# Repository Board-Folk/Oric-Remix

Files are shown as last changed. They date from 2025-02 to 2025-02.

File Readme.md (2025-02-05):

# Oric Remix

An updated Oric-1 / Oric Atmos board

** Work-in-progress **

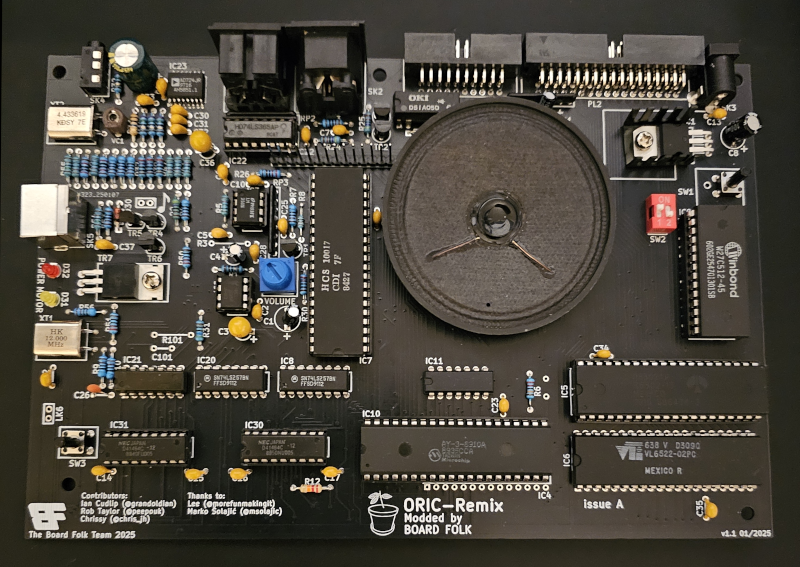
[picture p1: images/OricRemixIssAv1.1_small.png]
Image of build version 1.1 board in black


This repository contains the Bill-of-Materials (BOM), Gerbers and Kicad files for an updated Tangerine Oric motherboard found in the Oric-1 and Oric Atmos computers. The board is compatible for system ROM, in software and in form factor with the original board. Improvements include integration of service manual modifications, updated RAM and ROM layout and composite video, with the added intention to make it easier to build. It does not replace any of the core chips including the ULA which is still required.

More information to follow. This has been tested as it is to the best of our ability so far, but as none of the development team currently have any external expansion bus peripherals this has to be considered not fully tested, so build and use with that in mind. We'd like some help to change that!

## Revisions

* Version 1.1 Initial Public Release

### Version 1.1 Modifications from Original

* LM7805 voltage regulator
* 27C512 ROM with 4 bank selector
* Additional AY-3-8910 socket
* Integrated tape mods (inc service manual)
* Replacement /ROMDIS logic
* AD724 composite & stereo sound output
* Speaker volume control
* 4464 RAM
* Additional system reset button
* Commodore 1531 tape interface (optional - original remains on the board)

## Modification Notes

### LM7805

The original Oric boards regulated the negative power rail using a 7905 voltage regulator, keeping the positive rail common across the board and to the power supply. This has been replaced with a 7805 regulator making the ground common instead. This makes it easier to replace the regulator with something more modern and common. It has to be noted though this may cause issues sharing a power adapter with other expansions that also regulate on the negative rail, depending on how they connect to the system through the interface port. If this is the case separate power adapters should be used. We'll be testing this in time, and we're pretty sure this will have caused terrible problems for the original board too as the original regulator doesn't make a whole lot of sense for driving logic.

### ROM replacement and /ROMDIS updated

For the use of EPROMs and the bank selector, /ROMDIS was updated, the logic which allows external expansions to disable the system ROM. This uses IC11 which can no longer be omitted.

A 27C512 EEPROM can be used in chunks of 16KB selectable with the DIP switch. To compile a ROM of this kind, simply concatenate 4 16KB ROM images together, for example in DOS, copy /b rom1.bin+rom2.bin+rom3.bin+rom4.bin bigrom.bin to give you a 64KB file and select each 16KB banks with the switches as binary.

### AY-3-8910 socket

The AY-3-8910 can be fitted instead of the AY-3-8912 sound chip. There's no difference in function and good ones can be found more cheaply.

### Integrated Tape Mods

There were two tape mods, one from the the service manual and one from an assembled original, which have been included on the board. From the service manual page 71, modification 8, R11 and C19 "Improved Cassette Loading". R101 and C101 were also found on an original assembled board. This second mod should not be fitted for boards assembled with the 1531 tape interface.

### AD724 Composite Output

The original PROM based composite generation for the RF modulator wasn't good at all. This has been replaced with an AD724 and a 3.5mm TRRS output jack which also includes Stereo audio out, in the same channel configuration as you'd have on an Amstrad CPC464/6128. Sleeve is ground you'll need an OMTP wired cable connection.

### Speaker Volume Control

The original Oric was too loud. This adjusts the volume. Within the footprint of the volume control, there's a header for connection of an external potentiometer instead.

### System Reset Button

An additional push button has been added, with alternative pin header LK6 for external connection. This is a separate CPU reset, the original pulls down /NMI.

### Commodore 1531 Tape Port

To cut a long story short, tape support isn't great on the Oric, a source tape has to be near perfect, or you need a Maxduino. There was space on the board after all the other mods, and the schematics fitted well. It doesn't need to be fitted which is why the BOM is listed separately. The original tape connection and relay are still there with the original 7 pin DIN on the back. You can fit both fine, so long as R101 and C101 aren't fitted. It's just a cool feature and nice to have, though might upset some purists.

## Keyboard

We'll try get a keyboard replica done as soon as we can, modified for the use of MX or compatible keyswitches. There's at least one other replica already available on the internet.

A prototype PS/2 interface has been completed and works which isn't any use with an original case, but at least makes a functional system. The board also has provision for USB, the code for which hasn't been completed yet. This prototype will be uploaded soon. Still trying to work out how this will work out for a final version and whether that can fit inside a case.

## Build Notes

** Coming soon **

## BOM

### Main BOM

Main BOM including items for Commodore 1531 Cassette. See below. Resistors 1/4W. Ceramic caps 5.08mm. Electrolytics and Tants all radial.

|Qty|Reference(s)|Value|Type|Notes|
|:--:|:--:|:--:|:--:|:--:|
|1|R1|10R|Resistor||
|1|R2|4K7|Resistor||
|10|R4,R7,R9-R11,R13,R40-R42,R56|1K|Resistor||
|1|R101|1K|Resistor|Do not fit for C1531|
|6|R5,R43-R45,R47,R49|10K|Resistor||
|1|R6|220K|Resistor||
|1|R8|100K|Resistor||
|3|R12,R46,R48|22K|Resistor||
|2|R24,R25|47K|Resistor||
|1|R26|2K2|Resistor||
|1|R30|220R|Resistor||
|3|R37-R39|270R|Resistor||
|1|R31|560R|Resistor||
|4|R32,R34-R36|75R|Resistor||
|1|C8|100uF 16V|Electrolytic||
|1|C4|2.2uF 16V|Electrolytic||
|1|C21|10uF 16V|Electrolytic||
|1|C1|22uF 16V|Electrolytic||
|1|C24|220uF 16V|Electrolytic||
|2|C3,C36|100uF Tant|Tantalum||
|1|C33|10pF|Ceramic||
|1|C26|120pF|Ceramic||
|1|C19|2.2nF|Ceramic||
|1|C101|2.2nF|Ceramic|Do not fit for C1531|
|1|C5|10nF|Ceramic||
|1|C9|220nF|Ceramic||
|5|C25,C28,C30-C32|100nF|Ceramic||
|14|C2,C7,C10-C17,C22-C23,C34,C35|47nF|Ceramic||
|1|VC1|5-20pF Trimmer|Trimmer|CVN6500|
|1|D1|1N4148|Small Signal Diode||
|1|D32|3mm LED|LED||
|1|IC1|LM7805|Voltage Regulator||
|1|IC2|LM386|IC||
|1|IC3|LM358|IC||
|1|IC4|AY-3-8912|IC|IC4 or IC10|
|1|IC10|AY-3-8910|IC|Not both|
|1|IC5|6502A|IC||
|1|IC6|6522A|IC||
|1|IC7|HCS10017|IC||
|2|IC8,IC20|74LS257|IC||
|1|IC9|27C128-27C512 ROM|IC||
|1|IC11|74LS00|IC|Clock and /ROMDIS (now a requirement)|
|1|IC21|74LS04|IC||
|1|IC22|74LS365|IC||
|1|IC23|AD724JR|IC||
|1|IC30,IC31|4464 RAM|IC||
|3|TR1-TR3|BC549|Transistor||
|1|RP1|2K2 SIP8 Bussed|Resistor Network||
|1|RP2|220R SIP8 Isolated|Resistor Network||
|1|RP3|10K SIP8 Isolated|Resistor Network||
|1|RV2|5K/10K 3386 Potentiometer|Potentiometer|5K recommended|
|1|SW1|Reset Switch (NMI)|Push Switch|Original or 6mm Push Switch|
|1|SW2|2 position DIP4 Switch|DIP Switch|Optional ROM Bank Selector 0-3 128Kb/512Kb|
|1|SW3|Reset Switch (System)|Push Switch|6mm Push Switch|
|1|RL1|Oki D51A05P|Relay||
|1|LS1|Philips AD2071/Z25|Speaker||
|1|XT1|12MHz|Crystal|HC-49/U recommended|
|1|XT2|4.43MHz|Crystal|HC-49/U recommended|
|1|SK1|5 pin DIN Socket|Socket||
|1|SK2|7 pin DIN Socket|Socket|Short, board pins 2 row, needs recommendation|
|1|SK3|2.1mm DC Barrel Jack|Socket||
|1|SK4|3.5mm TRRS Jack|Socket|PJ320A for OMTP connection|
|1|PL1|2x10 right angle pin header|Header||
|1|PL2|2x17 right angle header|Header||
|1|PL3|14 pin header|Header||

### Commodore 1531 Port BOM

|Qty|Reference(s)|Value|Type|Notes|
|:--:|:--:|:--:|:--:|:--:|
|2|R50,R51|220R|Resistor||
|1|R53|1K|Resistor||
|2|R54,R55|1K5|Resistor||
|1|C37|100nF|Ceramic||
|1|D30|1N4737A|Zener Diode|7.5V|
|1|D31|3mm LED|LED|Motor LED|
|2|TR4,TR5|BC547|Transistor||
|1|TR6|BC337|Transistor||
|1|TR7|TIP29|Transistor|D880 Substitute|
|1|SK5|7 pin mini-DIN|Socket||

## Links

   [Finedon Electronics - Short 7 pin DIN socket](https://www.ebay.co.uk/itm/185588182650) <br>
   [Mike Brown's Diagnostic ROM](https://oric.signal11.org.uk/html/diagrom.htm)

## Credits

Original replica PCB Layout by Rob Taylor (@peepouk) with modifications by Ian Cudlip (@grandoldian). Original PCB, research, assistance and documentation from Chrissy (@chris_jh). Schematics recreated and modifications by Ian Cudlip with suggestions and testing from Chrissy.

## Thanks

* "More Fun Making It" Lee (@morefunmakingit) 
* Marko Šolajić (@msolajic)
* The Board Folk Team

## Legal

As the product of this project is a replica of a proprietary product, the the author makes no claim of copyright to the schematics nor PCB layouts and releases these into the public domain, solely for the purposes of study and historical preservation.

You are free to produce PCBs based on this project's designs at your own risk and without limitation, for your own use or for sale and/or repair at a reasonable price. Attribution is appreciated. The authors are not obliged to provide support of any kind. 

Under no circumstances will the authors be held responsible or liable in any way for losses, damages or costs resulting from the use of the information and/or resources of this project. 

The resources are provided "as-is" without warranty of any kind, either expressed or implied, including, but not limited to, the implied warranties of merchantability and fitness for a particular purpose.

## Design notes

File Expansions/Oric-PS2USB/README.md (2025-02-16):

# Oric-PS2USB

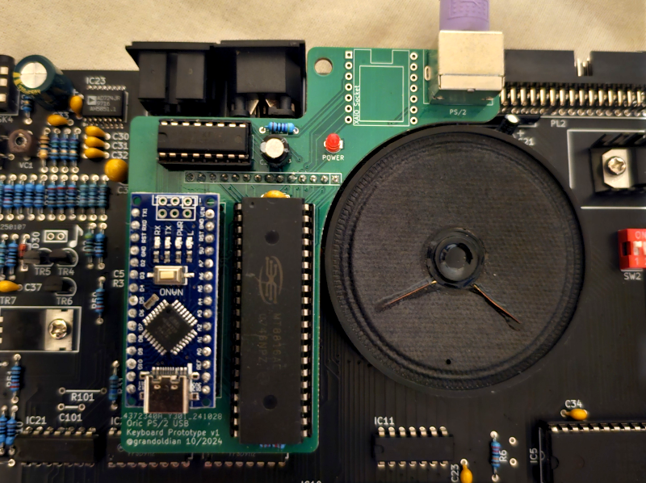
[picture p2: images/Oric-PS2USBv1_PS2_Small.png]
Image of PS2 build version 1 board in green


This is currently a prototype board to prove the schematic and code for doing something a bit better. The board contains footprints for both the Arduino Nano and Mini-DIN socket for PS/2 and the Seediuno Xiao for USB. Only populate one or the other.

It won't fit in an original case - it's not intended for that. It's suitable to get going with the Oric if you've no keyboard available - board only if you like. Better than no keyboard at all. The main board will need a 14 pin header fitting with pins long enough to reach the socket, approx 14mm above the component side of the board.

So far only the code for the Nano PS/2 assembly has been completed.

In the future, alongside more useful maybe a much reduced version in size we'll also do an MX keyboard similar to that of the Atmos - though this has already been done by others if you Google.

## BOM

The BOM is quite simple.

### PS/2

|Qty|Reference(s)|Value|Type|Notes|
|:--:|:--:|:--:|:--:|:--:|
|1|C1|47nF|Ceramic||
|1|C2|47uF|Electrolytic||
|1|R1|470R|Resistor||
|1|R2|10K|Resistor||
|1|D17|LED|3MM LED||
|1|U1|MT8816AE1|IC|DIP-40 Version|
|1|U2|Nano|Arduino||
|1|U3|CD4051|IC||
|1|PL1|14 pin socket|Socket Header||
|1|J3|6 pin Mini-DIN Socket|PS/2 Socket||

### USB

To follow.

## Code

The Arduino folder contains the code for the PS/2 interface and can be loaded with Arduino IDE. This is based on C64Keyboard by Robert VanHazinga. Key mappings can be found in keymapping.h - these are calculated from the spreadsheet "orickeyboard.ods" also in the Arduino folder.

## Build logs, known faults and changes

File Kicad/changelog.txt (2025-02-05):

Oric Remix Issue A Change Log
=============================

v1.1

Fix Volume Pot
Add VC1 PAL Oscillator Adjustment
C9 220nF AD724 Decoupler
Moved C3 now 100uF Tant
C36 now 100uF Tant
C21 Reset to 10uF
SW3, LK6 System Reset Switches

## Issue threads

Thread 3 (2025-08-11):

VSYNC hack

seclorum, 2025-08-11:
What about integrating a switch for the Orics’ VSYNC hack[1], like the OricExos[2] does, and which is supported in a few new games, such as Oricium[3], etc?

[1] https://www.defence-force.org/index.php?page=demos&demo=doublebuffer

[2] https://forum.defence-force.org/viewtopic.php?t=1880

[3] https://defenceforce.itch.io/oricium

grandoldian, 2025-09-06:
Thanks, hadn't seen this.

Will look into this if we do a new version if I can make a schematic out of that (and get it to fit).

Ian.

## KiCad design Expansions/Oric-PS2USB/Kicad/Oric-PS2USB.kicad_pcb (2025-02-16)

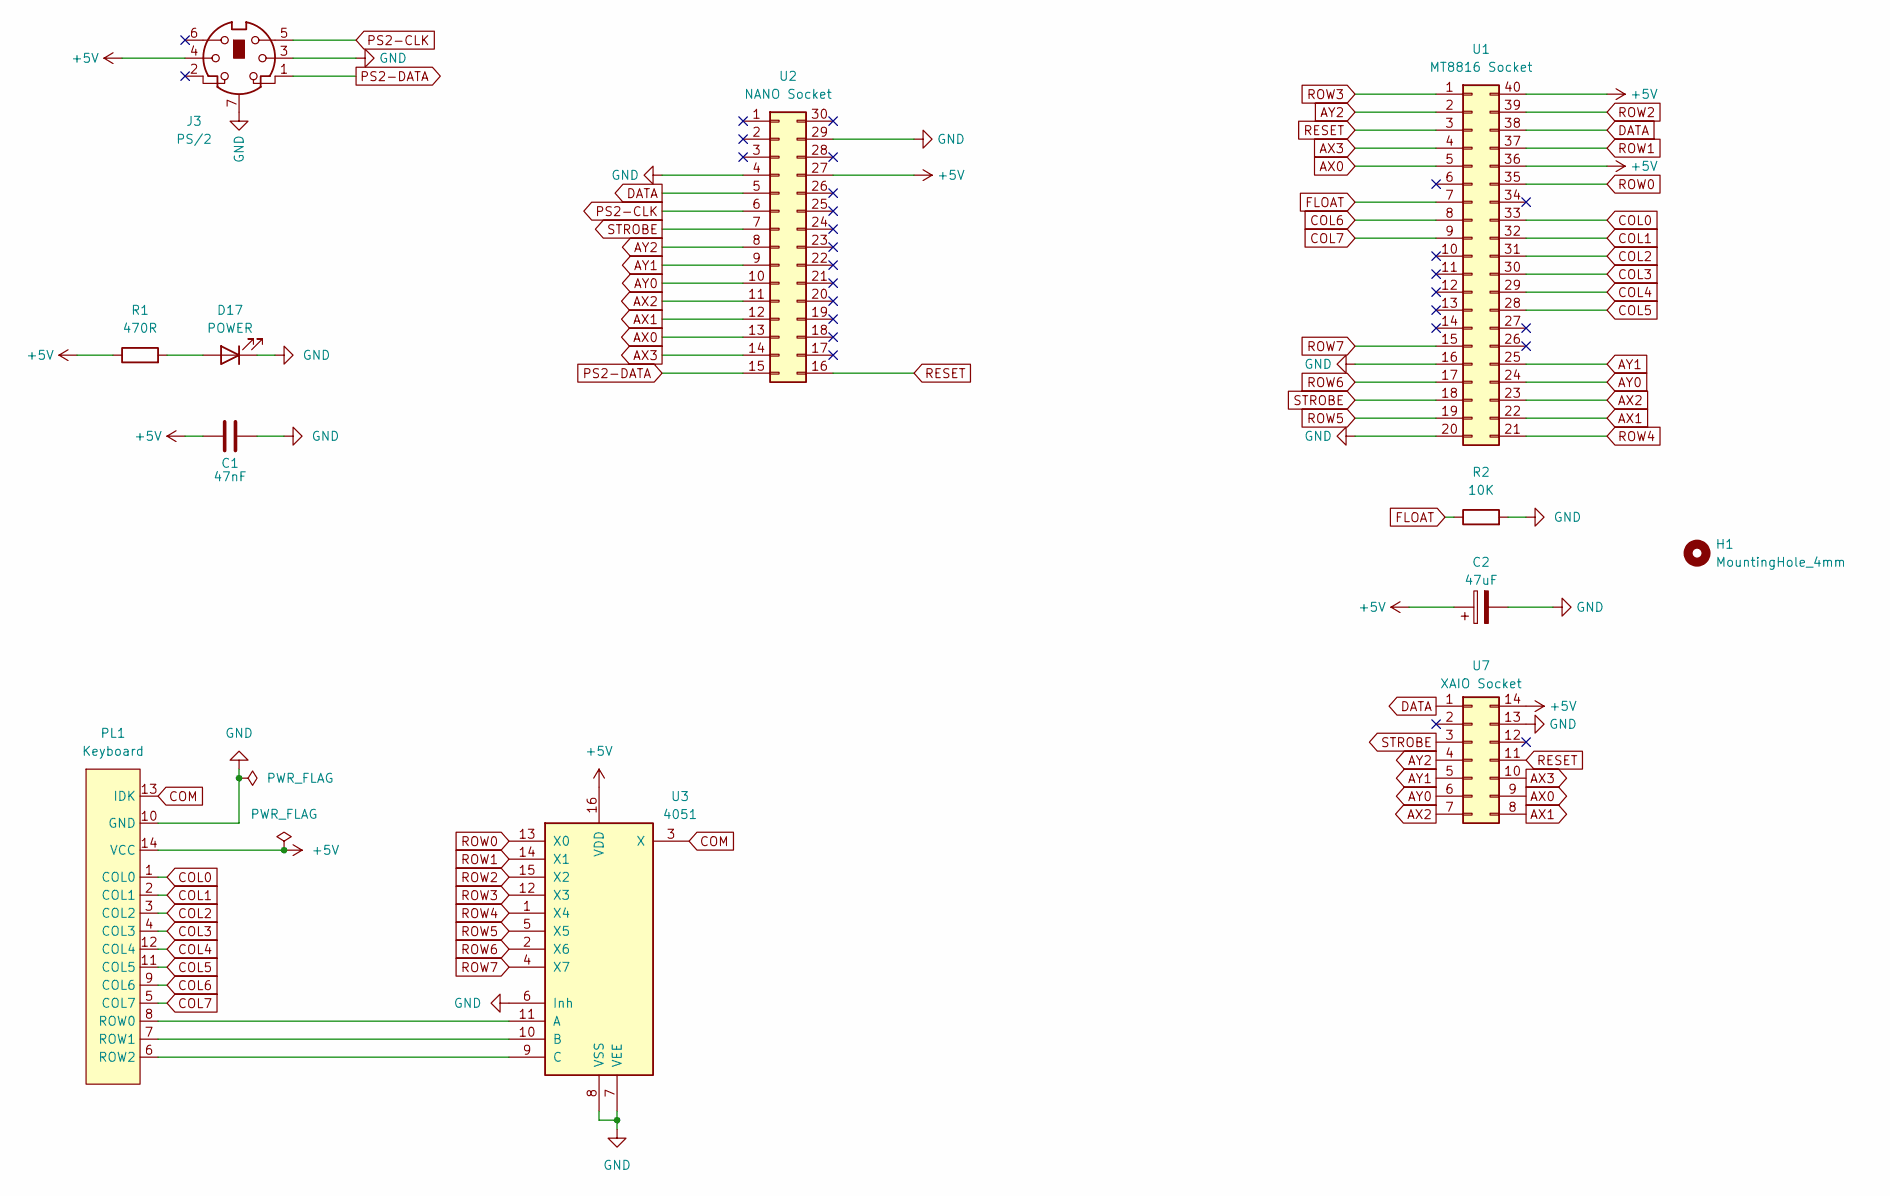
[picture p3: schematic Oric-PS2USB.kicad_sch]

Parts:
C1: 47nF; C_Disc_D4.3mm_W1.9mm_P5.00mm
C2: 47uF; CP_Radial_D5.0mm_P2.00mm
D17: POWER; LED_D3.0mm
H1: MountingHole_4mm
J3: PS/2; Connector_Mini-DIN_Female_6Pin_2rows
PL1: Keyboard; PinHeader_1x14_P2.54mm_Vertical
R1: 470R; R_Axial_DIN0204_L3.6mm_D1.6mm_P7.62mm_Horizontal
R2: 10K; R_Axial_DIN0204_L3.6mm_D1.6mm_P7.62mm_Horizontal
U1: MT8816 Socket; DIP-40_W15.24mm_Socket
U2: NANO Socket; Arduino_Nano_WithMountingHoles
U3: 4051; DIP-16_W7.62mm
U7: XAIO Socket; XAIO 14PIN

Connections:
+5V: C1.2, C2.1, J3.4, PL1.14 (VCC), R1.1, U1.36, U1.40, U2.27, U3.16 (VDD), U7.14
AX0: U1.5, U2.13, U7.9
AX1: U1.22, U2.12, U7.8
AX2: U1.23, U2.11, U7.7
AX3: U1.4, U2.14, U7.10
AY0: U1.24, U2.10, U7.6
AY1: U1.25, U2.9, U7.5
AY2: U1.2, U2.8, U7.4
COL0: PL1.1 (COL0), U1.33
COL1: PL1.2 (COL1), U1.32
COL2: PL1.3 (COL2), U1.31
COL3: PL1.4 (COL3), U1.30
COL4: PL1.12 (COL4), U1.29
COL5: PL1.11 (COL5), U1.28
COL6: PL1.9 (COL6), U1.8
COL7: PL1.5 (COL7), U1.9
COM: PL1.13 (IDK), U3.3 (X)
DATA: U1.38, U2.5, U7.1
FLOAT: R2.1, U1.7
GND: C1.1, C2.2, D17.1 (K), J3.3, J3.7, PL1.10 (GND), R2.2, U1.16, U1.20, U2.4, U2.29, U3.6 (Inh), U3.7 (VEE), U3.8 (VSS), U7.13
unnamed: D17.2 (A), R1.2
unnamed: PL1.8 (ROW0), U3.11 (A)
unnamed: PL1.7 (ROW1), U3.10 (B)
unnamed: PL1.6 (ROW2), U3.9 (C)
PS2-CLK: J3.5, U2.6
PS2-DATA: J3.1, U2.15
RESET: U1.3, U2.16, U7.11
ROW0: U1.35, U3.13 (X0)
ROW1: U1.37, U3.14 (X1)
ROW2: U1.39, U3.15 (X2)
ROW3: U1.1, U3.12 (X3)
ROW4: U1.21, U3.1 (X4)
ROW5: U1.19, U3.5 (X5)
ROW6: U1.17, U3.2 (X6)
ROW7: U1.15, U3.4 (X7)
STROBE: U1.18, U2.7, U7.3

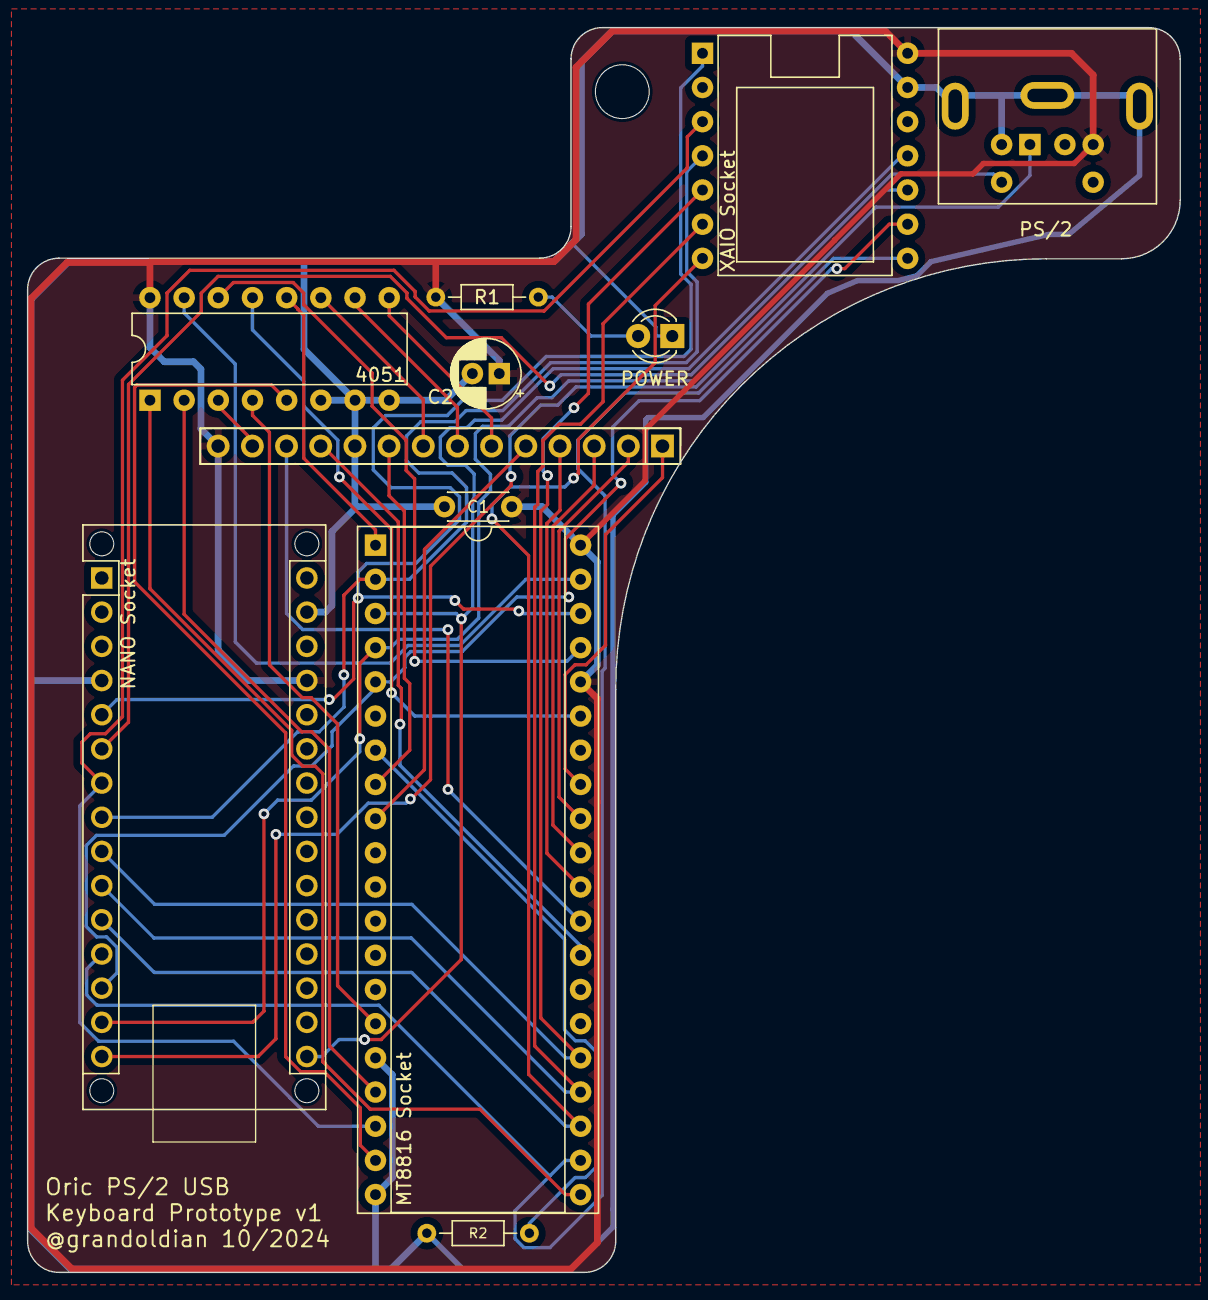
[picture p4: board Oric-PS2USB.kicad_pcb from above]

Board: 2 copper layers, 85.7 x 92.5 mm, 12 parts (0 on the bottom side), 36 nets.

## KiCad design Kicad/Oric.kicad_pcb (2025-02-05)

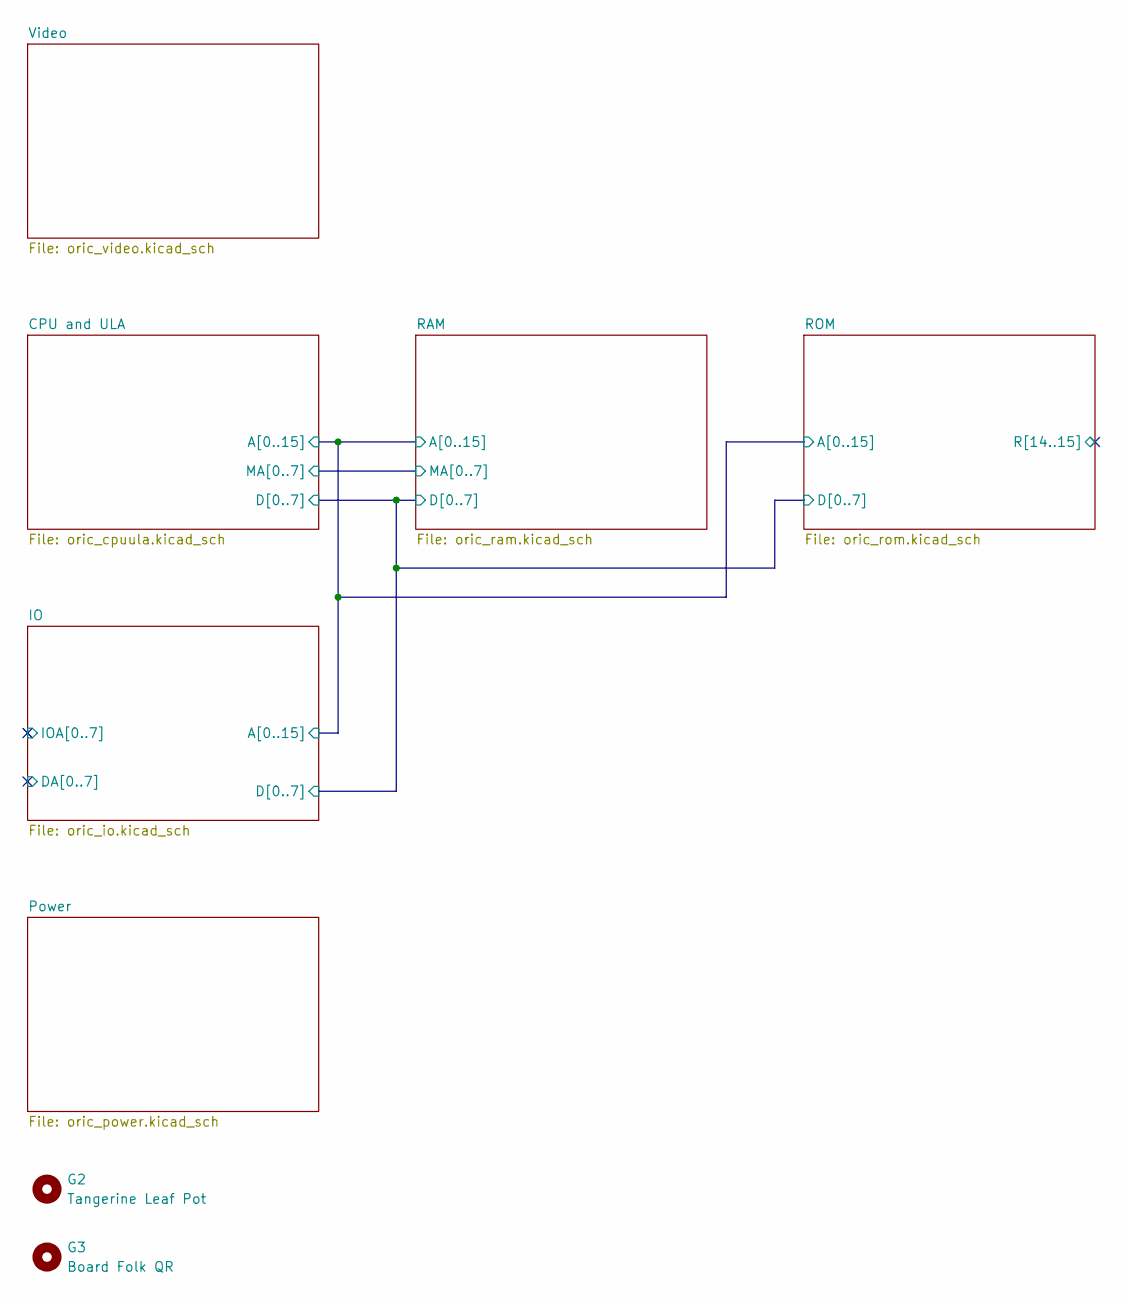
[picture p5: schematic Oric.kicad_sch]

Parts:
G2: Tangerine Leaf Pot; tangerineleafpot
G3: Board Folk QR; bf_qr14

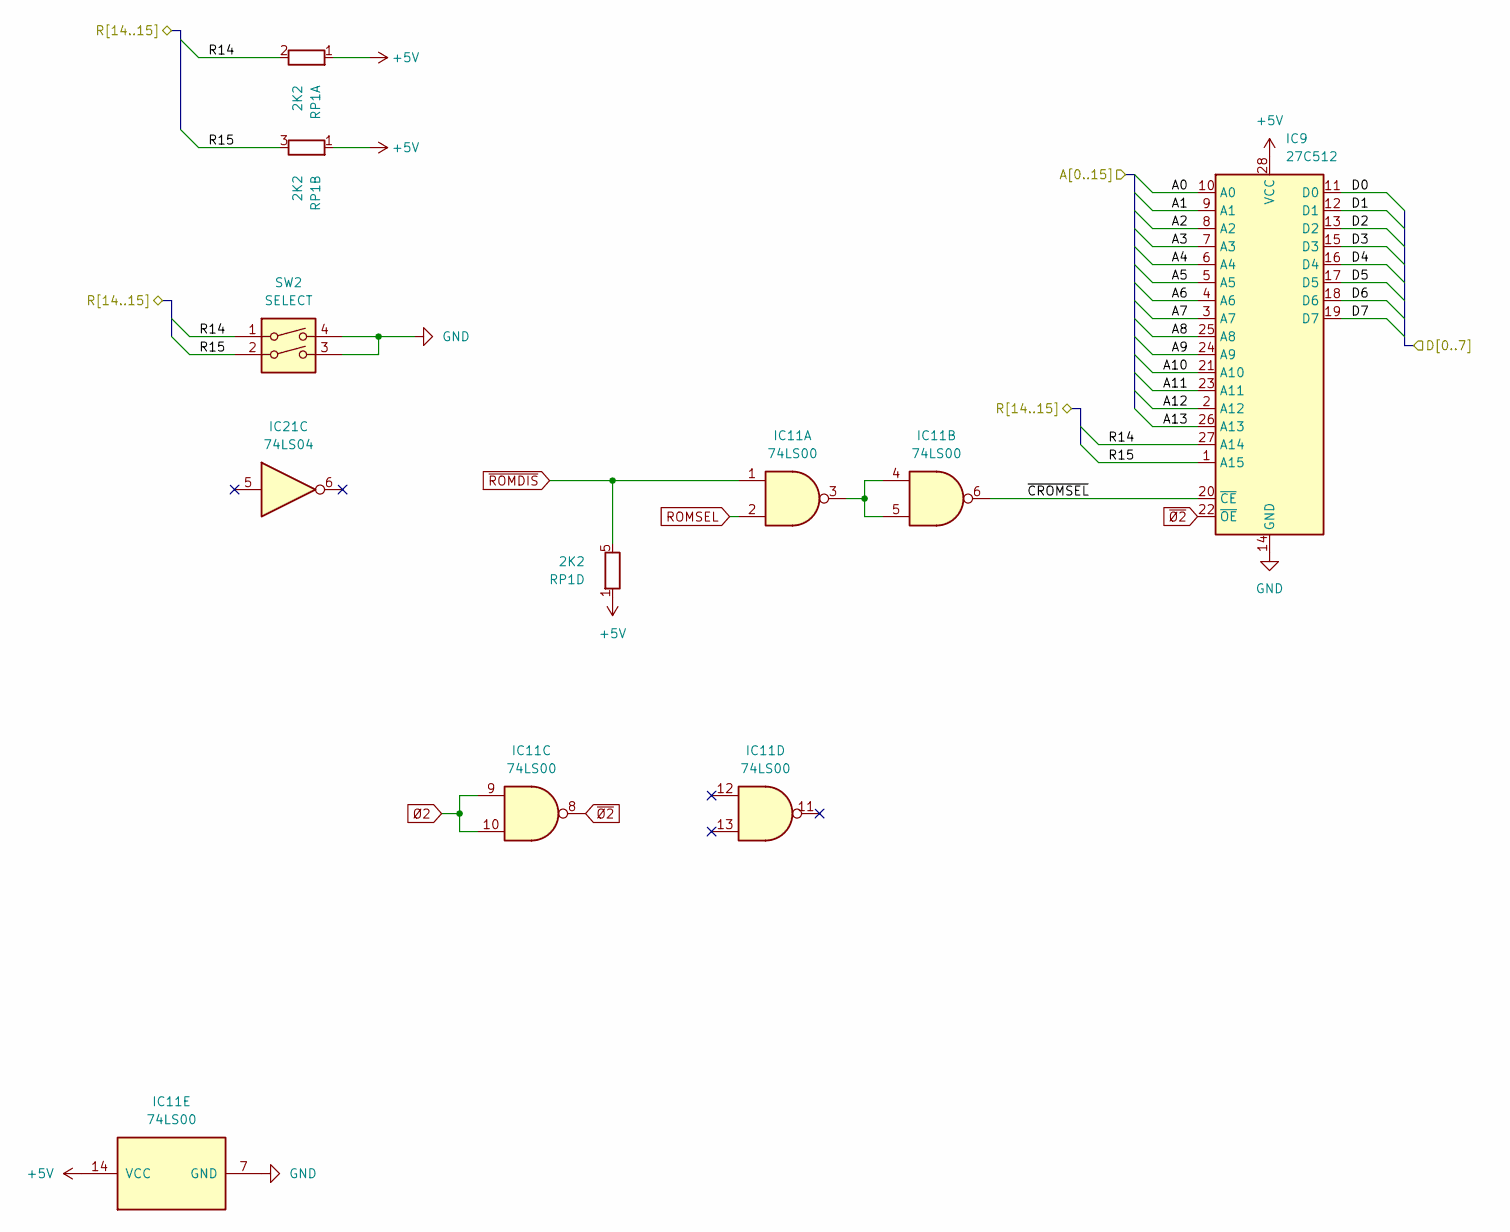
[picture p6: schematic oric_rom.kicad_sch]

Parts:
IC9: 27C512; DIP-28_W15.24mm
IC11: 74LS00; DIP-14_W7.62mm
IC21: 74LS04; DIP-14_W7.62mm
RP1: 2K2; R_Array_SIP8_Bussed
SW2: SELECT; ROM_Switch

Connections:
+5V: IC9.28 (VCC), IC11.14 (VCC), RP1.1 (R1); also elsewhere on the board
/CPU and ULA/A0: IC9.10 (A0); also elsewhere on the board
/CPU and ULA/A1: IC9.9 (A1); also elsewhere on the board
/CPU and ULA/A2: IC9.8 (A2); also elsewhere on the board
/CPU and ULA/A3: IC9.7 (A3); also elsewhere on the board
/CPU and ULA/A4: IC9.6 (A4); also elsewhere on the board
/CPU and ULA/A5: IC9.5 (A5); also elsewhere on the board
/CPU and ULA/A6: IC9.4 (A6); also elsewhere on the board
/CPU and ULA/A7: IC9.3 (A7); also elsewhere on the board
/CPU and ULA/A8: IC9.25 (A8); also elsewhere on the board
/CPU and ULA/A9: IC9.24 (A9); also elsewhere on the board
/CPU and ULA/A10: IC9.21 (A10); also elsewhere on the board
/CPU and ULA/A11: IC9.23 (A11); also elsewhere on the board
/CPU and ULA/A12: IC9.2 (A12); also elsewhere on the board
/CPU and ULA/A13: IC9.26 (A13); also elsewhere on the board
/CPU and ULA/D0: IC9.11 (D0); also elsewhere on the board
/CPU and ULA/D1: IC9.12 (D1); also elsewhere on the board
/CPU and ULA/D2: IC9.13 (D2); also elsewhere on the board
/CPU and ULA/D3: IC9.15 (D3); also elsewhere on the board
/CPU and ULA/D4: IC9.16 (D4); also elsewhere on the board
/CPU and ULA/D5: IC9.17 (D5); also elsewhere on the board
/CPU and ULA/D6: IC9.18 (D6); also elsewhere on the board
/CPU and ULA/D7: IC9.19 (D7); also elsewhere on the board
/ROM/R14: IC9.27 (A14), RP1.2 (R1.2), SW2.1
/ROM/R15: IC9.1 (A15), RP1.3 (R2.2), SW2.2
/ROM/~CROMSEL: IC9.20 (~CE), IC11.6
GND: IC9.14 (GND), IC11.7 (GND), SW2.3, SW2.4; also elsewhere on the board
unnamed: IC11.3, IC11.4, IC11.5
ROMSEL: IC11.2; also elsewhere on the board
~ROMDIS: IC11.1, RP1.5 (R4.2); also elsewhere on the board
~Ø2: IC9.22 (~OE), IC11.8
Ø2: IC11.9, IC11.10; also elsewhere on the board

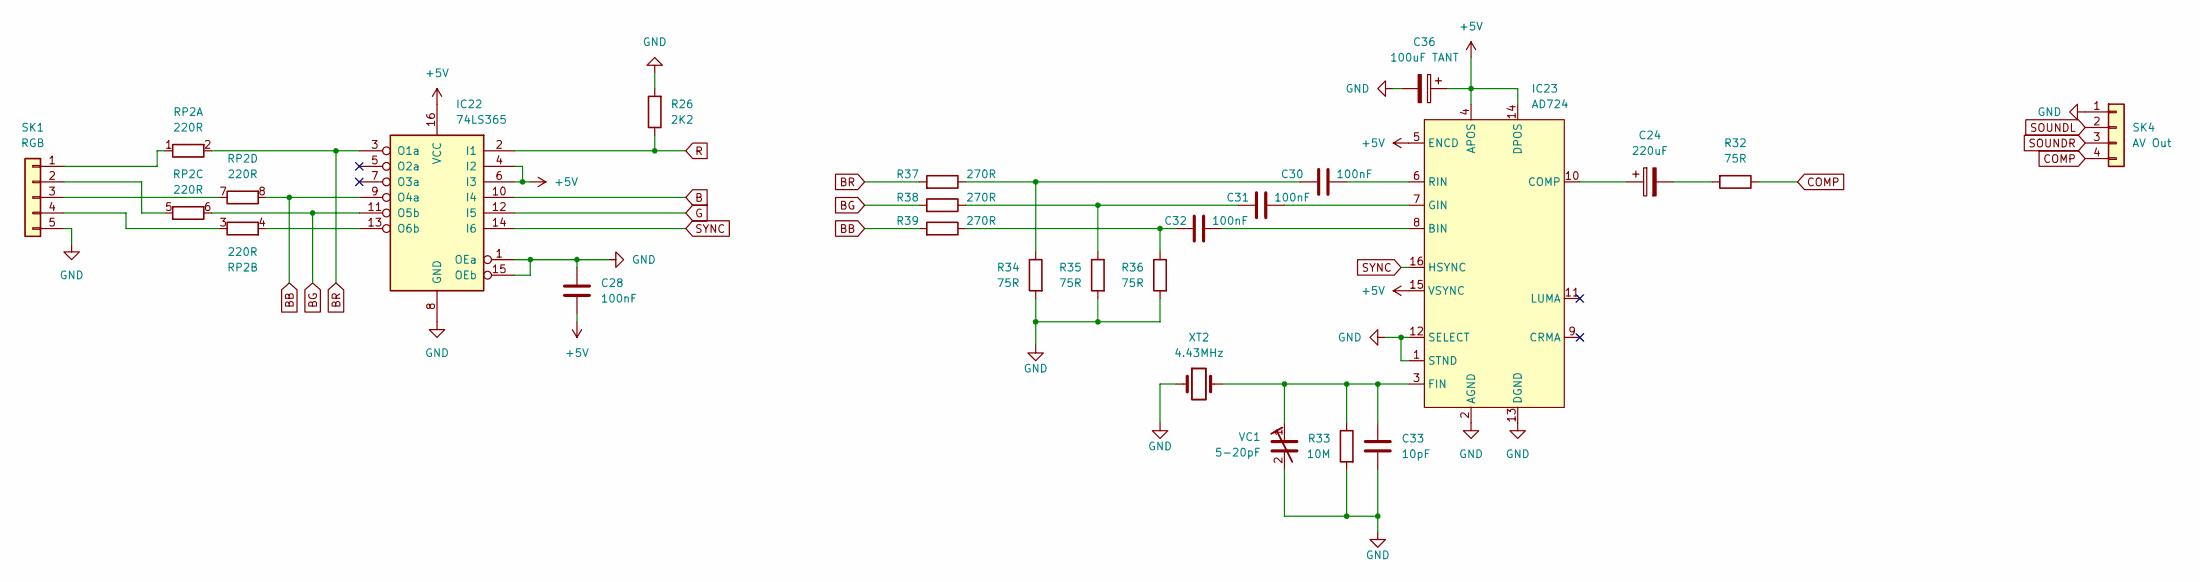
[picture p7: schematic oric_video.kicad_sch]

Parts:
C24: 220uF; Electrolytic Capacitor 5.00mm
C28, C30, C31, C32: 100nF; Ceramic Capacitor 5.00mm
C33: 10pF; Ceramic Capacitor 5.00mm
C36: 100uF TANT; Tantalum Capacitor 5.00mm
IC22: 74LS365; DIP-16_W7.62mm
IC23: AD724; SOIC-16W_7.5x10.3mm_P1.27mm
R26: 2K2; Resistor 10.16mm
R32, R34, R35, R36: 75R; Resistor 10.16mm
R33: 10M; Resistor 10.16mm
R37, R38, R39: 270R; Resistor 10.16mm
RP2: 220R; R_Array_SIP8_Isolated
SK1: RGB; SK1_5-Pin_DIN
SK4: AV Out; PJ320A
VC1: 5-20pF; CVN6500
XT2: 4.43MHz; Crystal

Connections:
+5V: C28.2, C36.1, IC22.4 (I2), IC22.6 (I3), IC22.16 (VCC), IC23.4 (APOS), IC23.5 (ENCD), IC23.14 (DPOS), IC23.15 (VSYNC); also elsewhere on the board
B: IC22.10 (I4); also elsewhere on the board
BB: IC22.9 (O4a), R39.2, RP2.8 (R4.2)
BG: IC22.11 (O5b), R38.2, RP2.6 (R3.2)
BR: IC22.3 (O1a), R37.2, RP2.2 (R1.2)
COMP: R32.1, SK4.4
G: IC22.12 (I5); also elsewhere on the board
GND: C28.1, C33.1, C36.2, IC22.1 (OEa), IC22.8 (GND), IC22.15 (OEb), IC23.1 (STND), IC23.2 (AGND), IC23.12 (SELECT), IC23.13 (DGND), R26.2, R33.2, R34.2, R35.2, R36.2, SK1.5, SK4.1, VC1.2, XT2.1; also elsewhere on the board
unnamed: C24.2, R32.2
unnamed: C30.1, R34.1, R37.1
unnamed: C31.1, R35.1, R38.1
unnamed: C32.1, R36.1, R39.1
unnamed: IC22.13 (O6b), RP2.4 (R2.2)
unnamed: C32.2, IC23.8 (BIN)
unnamed: C24.1, IC23.10 (COMP)
unnamed: C33.2, IC23.3 (FIN), R33.1, VC1.1, XT2.2
unnamed: C31.2, IC23.7 (GIN)
unnamed: C30.2, IC23.6 (RIN)
unnamed: RP2.1 (R1.1), SK1.1
unnamed: RP2.3 (R2.1), SK1.4
unnamed: RP2.5 (R3.1), SK1.2
unnamed: RP2.7 (R4.1), SK1.3
R: IC22.2 (I1), R26.1; also elsewhere on the board
SOUNDL: SK4.2; also elsewhere on the board
SOUNDR: SK4.3; also elsewhere on the board
SYNC: IC22.14 (I6), IC23.16 (HSYNC); also elsewhere on the board

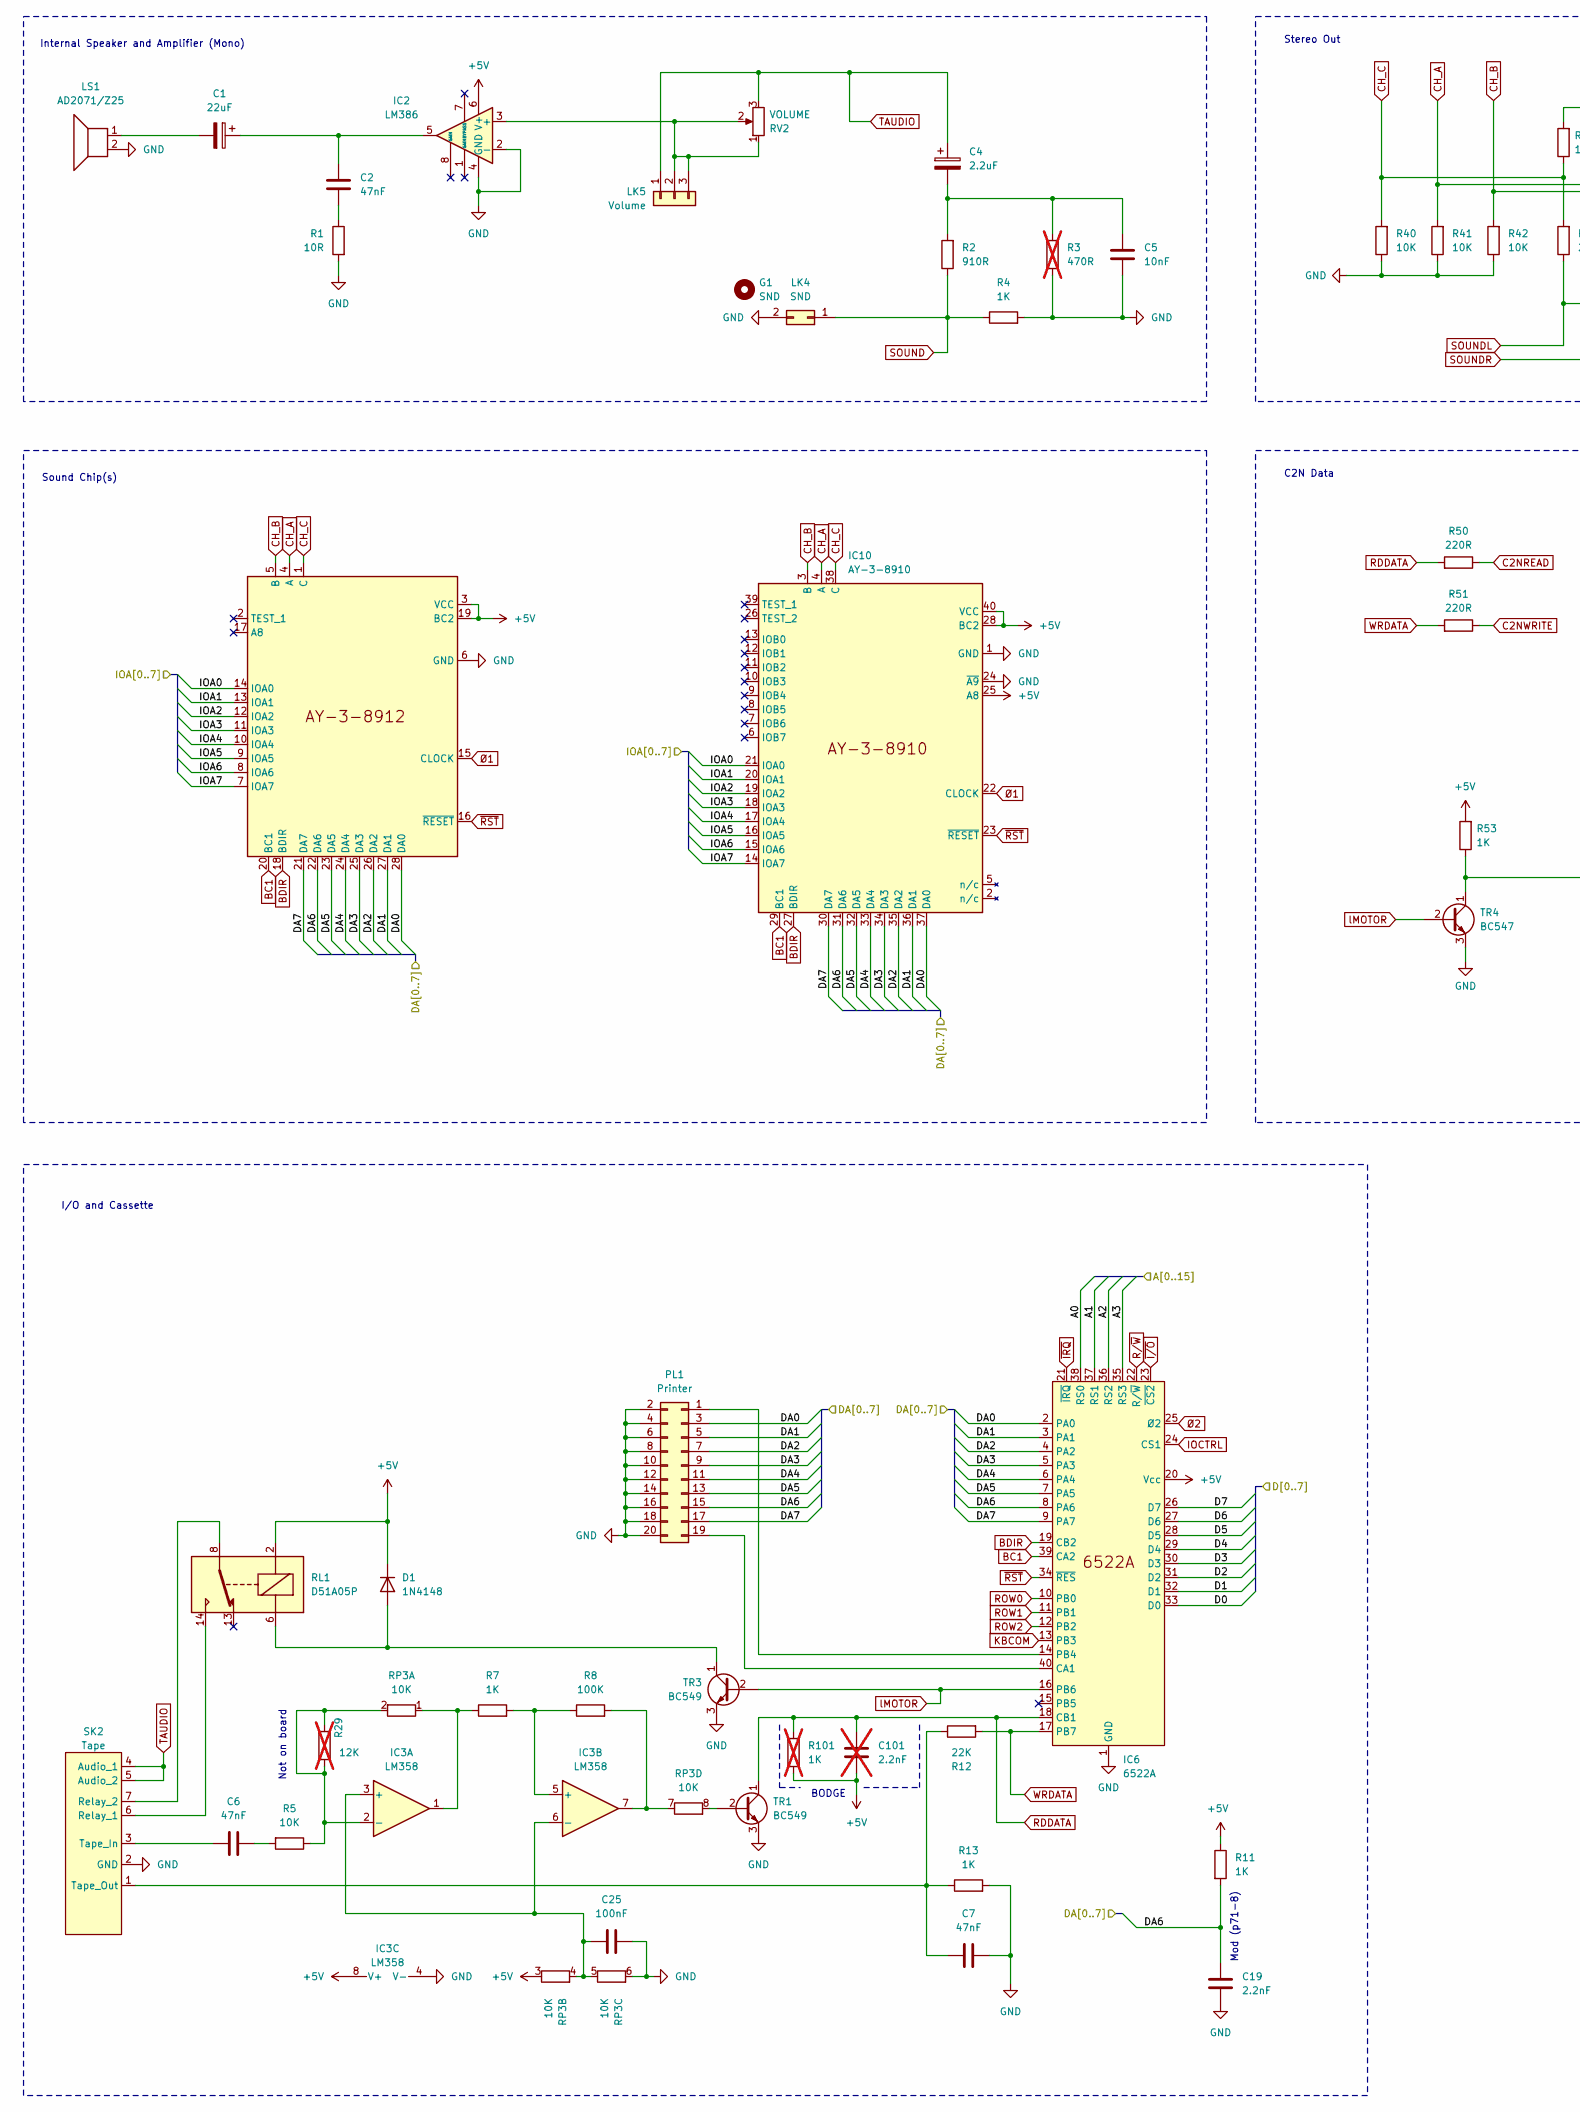
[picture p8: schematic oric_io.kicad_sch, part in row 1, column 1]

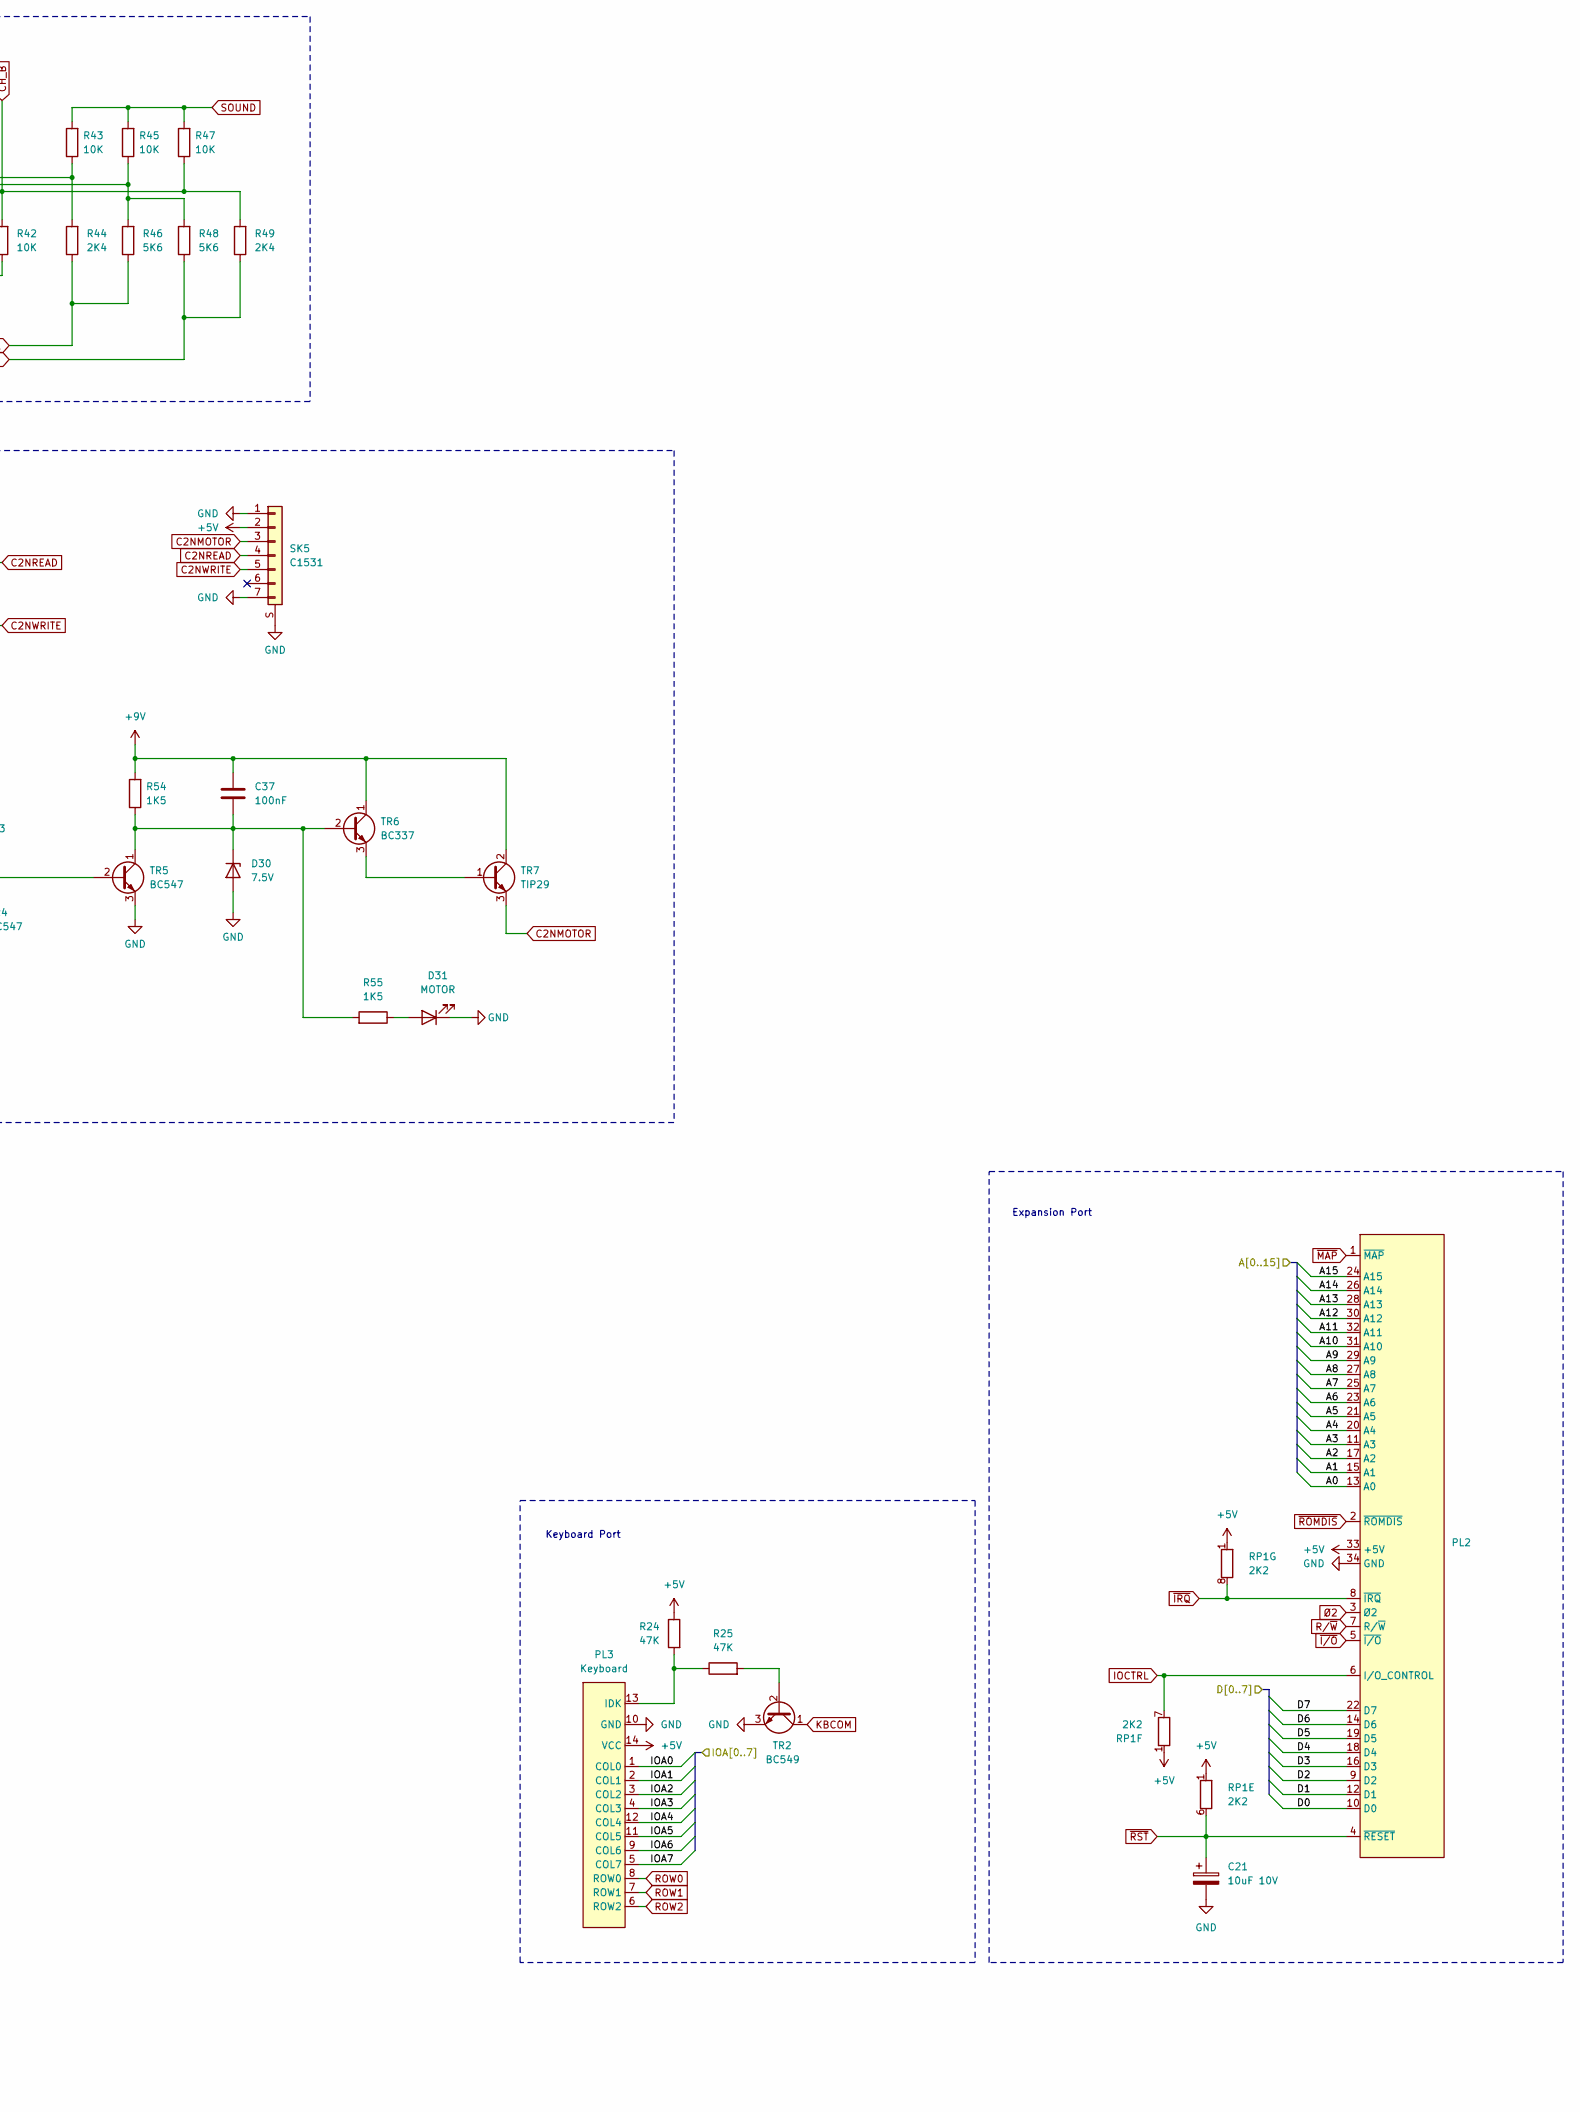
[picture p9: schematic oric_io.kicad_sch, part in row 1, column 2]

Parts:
C1: 22uF; Electrolytic Capacitor 5.00mm
C2, C6, C7: 47nF; Ceramic Capacitor 5.00mm
C4: 2.2uF; Tantalum Capacitor 5.00mm
C5: 10nF; Ceramic Capacitor 5.00mm
C19: 2.2nF; Ceramic Capacitor 5.00mm
C21: 10uF 10V; Electrolytic Capacitor 5.00mm
C25, C37: 100nF; Ceramic Capacitor 5.00mm
C101: 2.2nF; Ceramic Capacitor 5.00mm; not fitted
D1: 1N4148; Diode_7.62mm
D30: 7.5V; Diode_7.62mm
D31: MOTOR; LED_D3.0mm
G1: SND; Tune
IC2: LM386; DIP-8_W7.62mm
IC3: LM358; DIP-8_W7.62mm
IC4: AY-3-8912; DIP-28_W15.24mm
IC6: 6522A; DIP-40_W15.24mm
IC10: AY-3-8910; DIP-40_W15.24mm
LK4: SND; PinHeader_1x02_P2.54mm
LK5: Volume; PinHeader_1x03_P2.54mm
LS1: AD2071/Z25; Speaker
PL1: Printer; PinHeader_2x10_P2.54mmo
PL2: PinHeader_2x17_P2.54mm
PL3: Keyboard; PinHeader_1x14_P2.54mm
R1: 10R; Resistor 10.16mm
R2: 910R; Resistor 10.16mm
R3: 470R; Resistor 10.16mm; not fitted
R4, R7, R11, R13, R53: 1K; Resistor 10.16mm
R5: 10K; Resistor 10.16mm
R8: 100K; Resistor 10.16mm
R12: 22K; Resistor 10.16mm
R24, R25: 47K; Resistor 10.16mm
R29: 12K; Resistor 10.16mm; not fitted
R40, R41, R42: 10K; Resistor 10.16mm; LCSC C482939
R43, R45, R47: 10K; Resistor 10.16mm; LCSC C84376
R44, R49: 2K4; Resistor 10.16mm; LCSC C84376
R46, R48: 5K6; Resistor 10.16mm; LCSC C114565
R50, R51: 220R; Resistor 10.16mm
R54, R55: 1K5; Resistor 10.16mm
R101: 1K; Resistor 10.16mm; not fitted
RL1: D51A05P; Relay
RP1: 2K2; R_Array_SIP8_Bussed
RP3: 10K; R_Array_SIP8_Isolated
RV2: VOLUME; Volume Control 3386
SK2: Tape; SK2 7-Pin_DIN
SK5: C1531; C1531 - 7-Pin Mini DIN
TR1, TR2, TR3: BC549; TO-92
TR4, TR5: BC547; TO-92
TR6: BC337; TO-92
TR7: TIP29; TIP29 TO-220

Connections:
+5V: C101.1, D1.1 (K), IC2.6 (V+), IC3.8 (V+), IC4.3 (VCC), IC4.19 (BC2), IC6.20 (Vcc), IC10.25 (A8), IC10.28 (BC2), IC10.40 (VCC), PL2.33 (+5V), PL3.14 (VCC), R11.1, R24.1, R53.2, R101.1, RL1.2, RP1.1 (R1), RP3.3 (R2.1), SK5.2; also elsewhere on the board
+9V: C37.1, R54.2, TR6.1 (C), TR7.2 (C); also elsewhere on the board
/CPU and ULA/A0: IC6.38 (RS0), PL2.13 (A0); also elsewhere on the board
/CPU and ULA/A1: IC6.37 (RS1), PL2.15 (A1); also elsewhere on the board
/CPU and ULA/A2: IC6.36 (RS2), PL2.17 (A2); also elsewhere on the board
/CPU and ULA/A3: IC6.35 (RS3), PL2.11 (A3); also elsewhere on the board
/CPU and ULA/A4: PL2.20 (A4); also elsewhere on the board
/CPU and ULA/A5: PL2.21 (A5); also elsewhere on the board
/CPU and ULA/A6: PL2.23 (A6); also elsewhere on the board
/CPU and ULA/A7: PL2.25 (A7); also elsewhere on the board
/CPU and ULA/A8: PL2.27 (A8); also elsewhere on the board
/CPU and ULA/A9: PL2.29 (A9); also elsewhere on the board
/CPU and ULA/A10: PL2.31 (A10); also elsewhere on the board
/CPU and ULA/A11: PL2.32 (A11); also elsewhere on the board
/CPU and ULA/A12: PL2.30 (A12); also elsewhere on the board
/CPU and ULA/A13: PL2.28 (A13); also elsewhere on the board
/CPU and ULA/A14: PL2.26 (A14); also elsewhere on the board
/CPU and ULA/A15: PL2.24 (A15); also elsewhere on the board
/CPU and ULA/D0: IC6.33 (D0), PL2.10 (D0); also elsewhere on the board
/CPU and ULA/D1: IC6.32 (D1), PL2.12 (D1); also elsewhere on the board
/CPU and ULA/D2: IC6.31 (D2), PL2.9 (D2); also elsewhere on the board
/CPU and ULA/D3: IC6.30 (D3), PL2.16 (D3); also elsewhere on the board
/CPU and ULA/D4: IC6.29 (D4), PL2.18 (D4); also elsewhere on the board
/CPU and ULA/D5: IC6.28 (D5), PL2.19 (D5); also elsewhere on the board
/CPU and ULA/D6: IC6.27 (D6), PL2.14 (D6); also elsewhere on the board
/CPU and ULA/D7: IC6.26 (D7), PL2.22 (D7); also elsewhere on the board
/IO/DA0: IC4.28 (DA0), IC6.2 (PA0), IC10.37 (DA0), PL1.3
/IO/DA1: IC4.27 (DA1), IC6.3 (PA1), IC10.36 (DA1), PL1.5
/IO/DA2: IC4.26 (DA2), IC6.4 (PA2), IC10.35 (DA2), PL1.7
/IO/DA3: IC4.25 (DA3), IC6.5 (PA3), IC10.34 (DA3), PL1.9
/IO/DA4: IC4.24 (DA4), IC6.6 (PA4), IC10.33 (DA4), PL1.11
/IO/DA5: IC4.23 (DA5), IC6.7 (PA5), IC10.32 (DA5), PL1.13
/IO/DA6: C19.1, IC4.22 (DA6), IC6.8 (PA6), IC10.31 (DA6), PL1.15, R11.2
/IO/DA7: IC4.21 (DA7), IC6.9 (PA7), IC10.30 (DA7), PL1.17
/IO/IOA0: IC4.14 (IOA0), IC10.21 (IOA0), PL3.1 (COL0)
/IO/IOA1: IC4.13 (IOA1), IC10.20 (IOA1), PL3.2 (COL1)
/IO/IOA2: IC4.12 (IOA2), IC10.19 (IOA2), PL3.3 (COL2)
/IO/IOA3: IC4.11 (IOA3), IC10.18 (IOA3), PL3.4 (COL3)
/IO/IOA4: IC4.10 (IOA4), IC10.17 (IOA4), PL3.12 (COL4)
/IO/IOA5: IC4.9 (IOA5), IC10.16 (IOA5), PL3.11 (COL5)
/IO/IOA6: IC4.8 (IOA6), IC10.15 (IOA6), PL3.9 (COL6)
/IO/IOA7: IC4.7 (IOA7), IC10.14 (IOA7), PL3.5 (COL7)
BC1: IC4.20 (BC1), IC6.39 (CA2), IC10.29 (BC1)
BDIR: IC4.18 (BDIR), IC6.19 (CB2), IC10.27 (BDIR)
C2NMOTOR: SK5.3, TR7.3 (E)
C2NREAD: R50.1, SK5.4
C2NWRITE: R51.1, SK5.5
CH_A: IC4.4 (A), IC10.4 (A), R41.2, R45.1, R46.2, R48.2
CH_B: IC4.5 (B), IC10.3 (B), R42.2, R47.1, R49.2
CH_C: IC4.1 (C), IC10.38 (C), R40.2, R43.1, R44.2
GND: C5.2, C7.2, C19.2, C21.2, C25.2, D30.2 (A), D31.1 (K), IC2.2 (-), IC2.4 (GND), IC3.4 (V-), IC4.6 (GND), IC6.1 (GND), IC10.1 (GND), IC10.24 (~A9), LK4.2, LS1.2, PL1.2, PL1.4, PL1.6, PL1.8, PL1.10, PL1.12, PL1.14, PL1.16, PL1.18, PL1.20, PL2.34 (GND), PL3.10 (GND), R1.2, R3.1, R4.2, R13.2, R40.1, R41.1, R42.1, RP3.6 (R3.2), SK2.2 (GND), SK5.1, SK5.7, SK5.S (SHIELD), TR1.3 (E), TR2.3 (E), TR3.3 (E), TR4.3 (E), TR5.3 (E); also elsewhere on the board
IOCTRL: IC6.24 (CS1), PL2.6 (I/O_CONTROL), RP1.7 (R6.2)
KBCOM: IC6.13 (PB3), TR2.1 (C)
unnamed: C1.1, C2.2, IC2.5
unnamed: C1.2, LS1.1
unnamed: C2.1, R1.1
unnamed: C4.2, C5.1, R2.2, R3.2
unnamed: C6.2, R5.2
unnamed: D1.2 (A), RL1.6, TR3.1 (C)
unnamed: C37.2, D30.1 (K), R54.1, R55.2, TR5.1 (C), TR6.2 (B)
unnamed: D31.2 (A), R55.1
unnamed: IC2.3 (+), LK5.2, LK5.3, RV2.1, RV2.2
unnamed: C25.1, IC3.3 (+), IC3.6 (-), RP3.4 (R2.2), RP3.5 (R3.1)
unnamed: IC3.2 (-), R5.1, R29.1, R29.2, RP3.2 (R1.2)
unnamed: IC3.5 (+), R7.2, R8.1
unnamed: IC6.40 (CA1), PL1.19
unnamed: IC6.14 (PB4), PL1.1
unnamed: PL3.13 (IDK), R24.2, R25.1
unnamed: IC3.1, R7.1, RP3.1 (R1.1)
unnamed: IC3.7, R8.2, RP3.7 (R4.1)
unnamed: RP3.8 (R4.2), TR1.2 (B)
unnamed: RL1.14, SK2.6 (Relay_1)
unnamed: RL1.8, SK2.7 (Relay_2)
unnamed: C6.1, SK2.3 (Tape_In)
unnamed: C7.1, R12.1, R13.1, SK2.1 (Tape_Out)
unnamed: R25.2, TR2.2 (B)
unnamed: R53.1, TR4.1 (C), TR5.2 (B)
unnamed: TR6.3 (E), TR7.1 (B)
RDDATA: C101.2, IC6.18 (CB1), R50.2, R101.2, TR1.1 (C)
ROW0: IC6.10 (PB0), PL3.8 (ROW0)
ROW1: IC6.11 (PB1), PL3.7 (ROW1)
ROW2: IC6.12 (PB2), PL3.6 (ROW2)
R/~W: IC6.22 (R/~W), PL2.7 (R/~W); also elsewhere on the board
SOUND: LK4.1, R2.1, R4.1, R43.2, R45.2, R47.2
SOUNDL: R44.1, R46.1; also elsewhere on the board
SOUNDR: R48.1, R49.1; also elsewhere on the board
TAUDIO: C4.1, LK5.1, RV2.3, SK2.4 (Audio_1), SK2.5 (Audio_2)
WRDATA: IC6.17 (PB7), R12.2, R51.2
lMOTOR: IC6.16 (PB6), TR3.2 (B), TR4.2 (B)
~IRQ: IC6.21 (~IRQ), PL2.8 (~IRQ), RP1.8 (R7.2); also elsewhere on the board
~I/O: IC6.23 (~CS2), PL2.5 (~I/O); also elsewhere on the board
~MAP: PL2.1 (~MAP); also elsewhere on the board
~ROMDIS: PL2.2 (~ROMDIS); also elsewhere on the board
~RST: C21.1, IC4.16 (~RESET), IC6.34 (~RES), IC10.23 (~RESET), PL2.4 (~RESET), RP1.6 (R5.2); also elsewhere on the board
Ø1: IC4.15 (CLOCK), IC10.22 (CLOCK); also elsewhere on the board
Ø2: IC6.25 (Ø2), PL2.3 (Ø2); also elsewhere on the board

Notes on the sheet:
I/O and Cassette
Expansion Port
Internal Speaker and Amplifier (Mono)
Sound Chip(s)
Stereo Out
Not on board
BODGE
Mod (p71-8)
Keyboard Port
C2N Data

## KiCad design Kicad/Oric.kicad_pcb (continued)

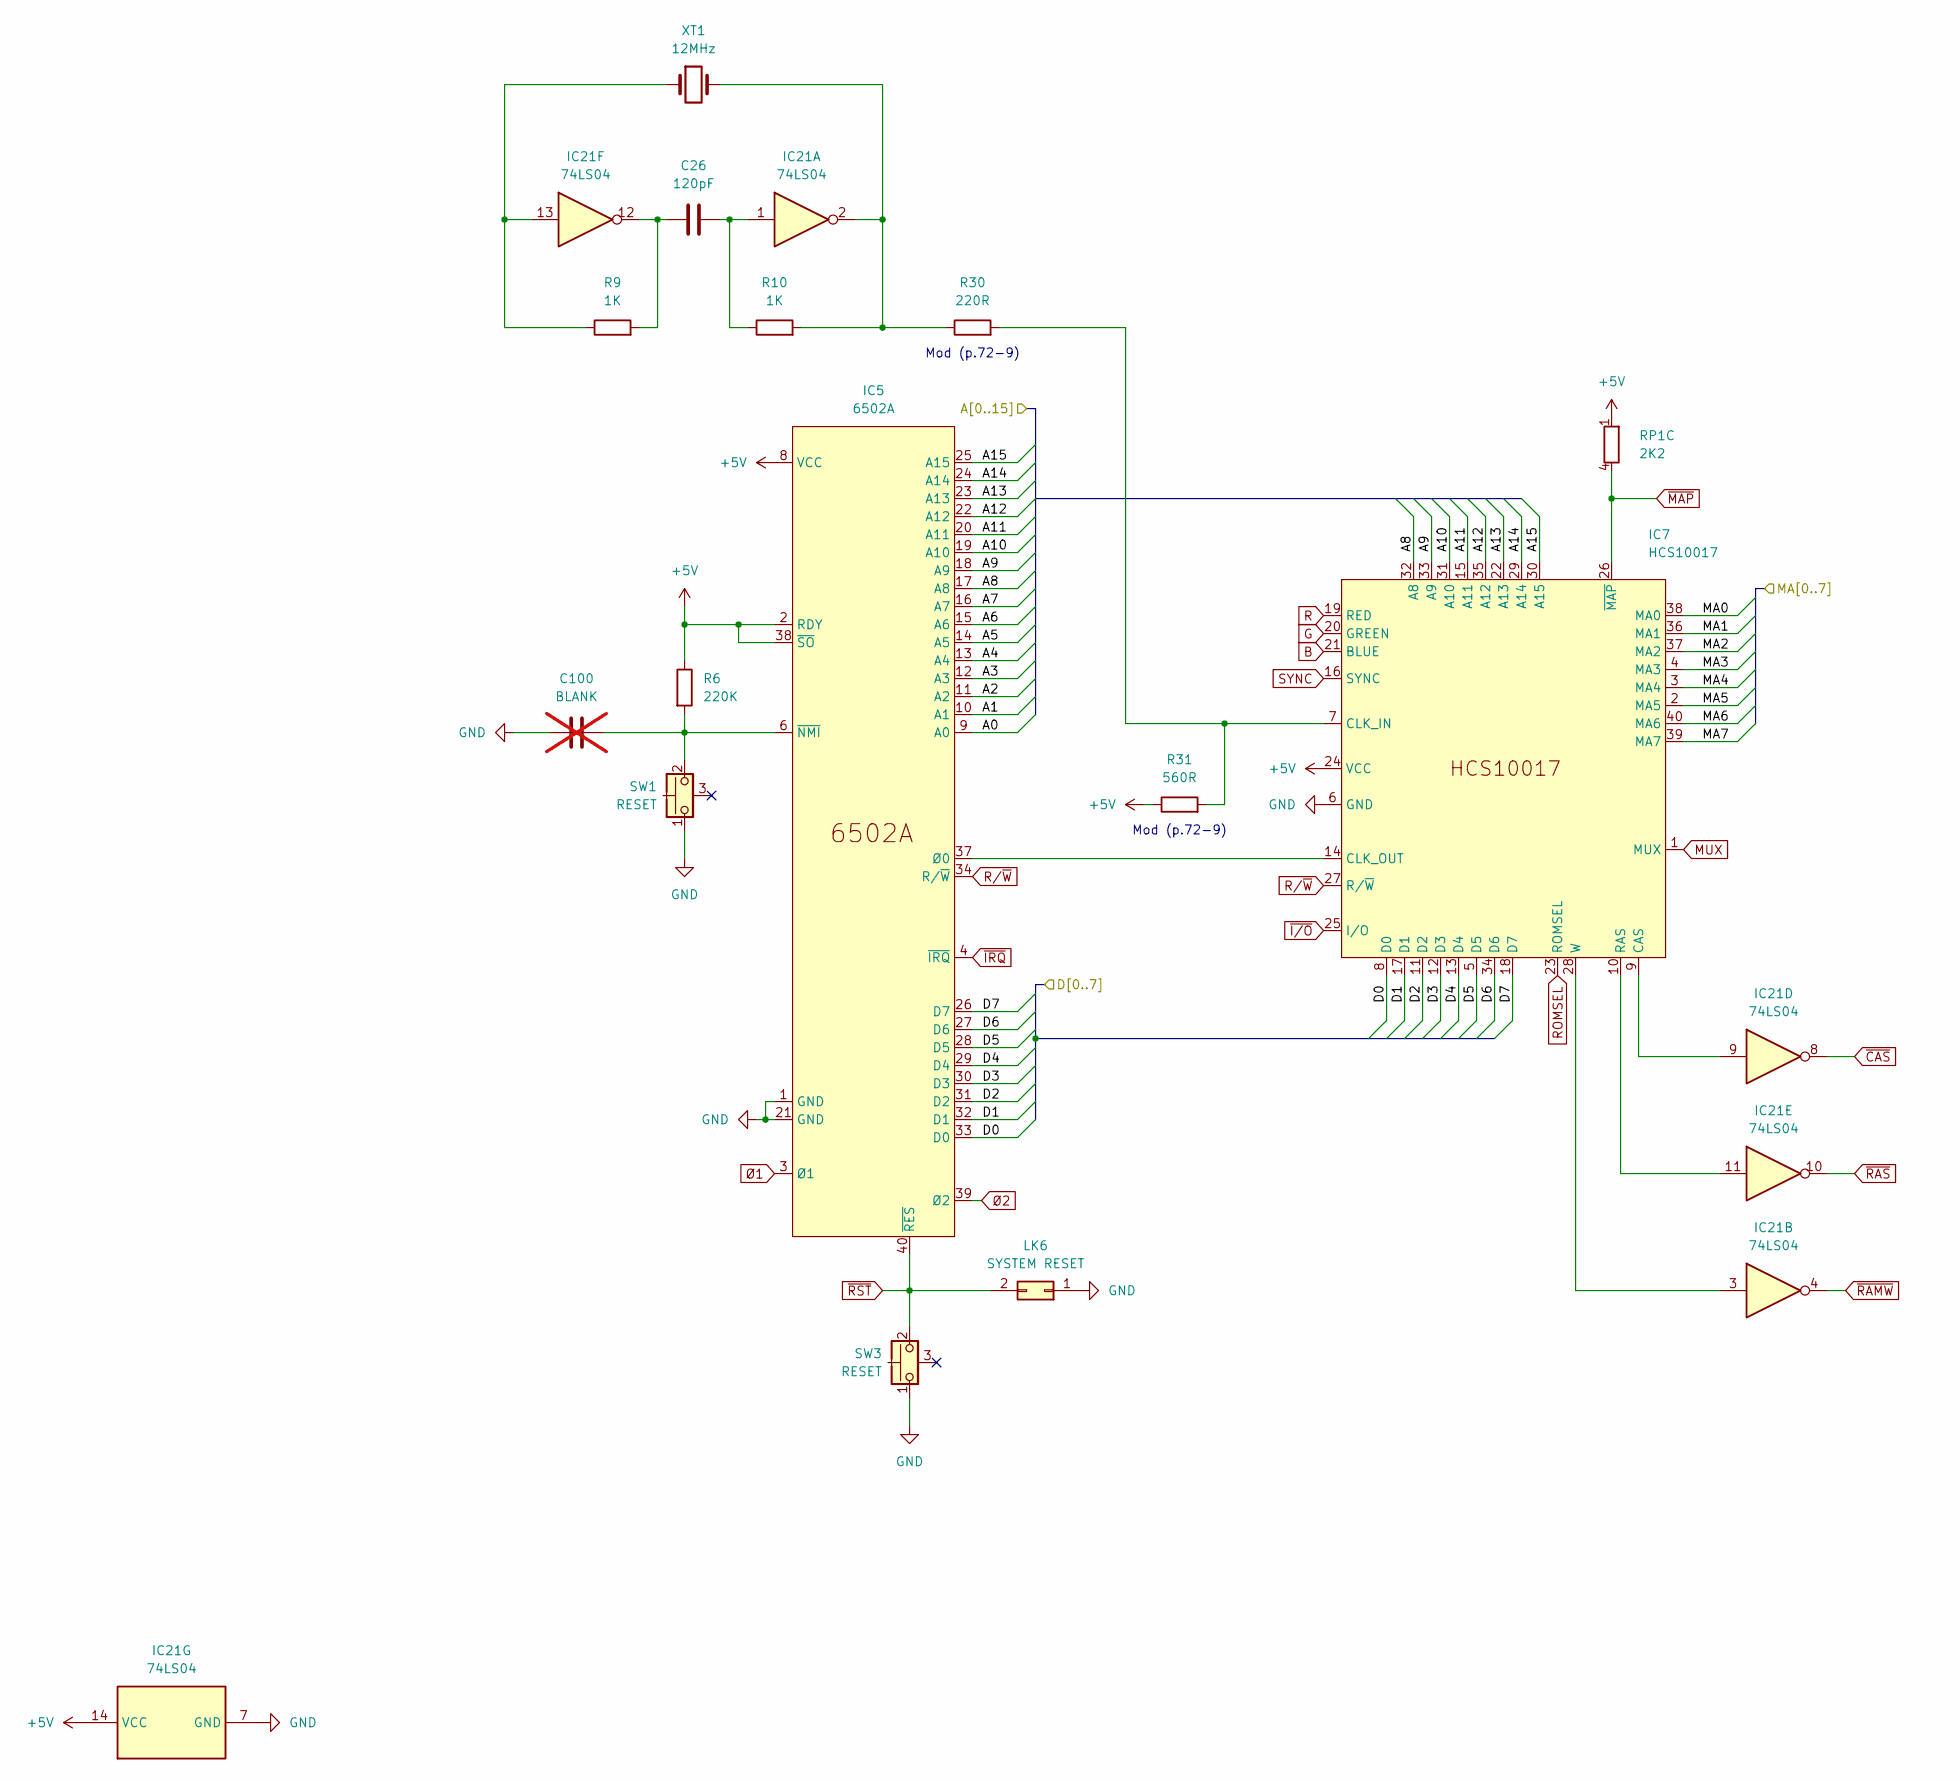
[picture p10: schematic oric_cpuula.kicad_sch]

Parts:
C26: 120pF; Ceramic Capacitor 5.00mm
C100: BLANK; Ceramic Capacitor 5.00mm_Blank; not fitted
IC5: 6502A; DIP-40_W15.24mm
IC7: HCS10017; DIP-40_W15.24mm
IC21: 74LS04; DIP-14_W7.62mm
LK6: SYSTEM RESET; PinHeader_1x02_P2.54mm
R6: 220K; Resistor 10.16mm
R9, R10: 1K; Resistor 10.16mm
R30: 220R; Resistor 10.16mm
R31: 560R; Resistor 10.16mm
RP1: 2K2; R_Array_SIP8_Bussed
SW1: RESET; Push Switch
SW3: RESET; Push Switch Simple
XT1: 12MHz; Crystal

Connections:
+5V: IC5.2 (RDY), IC5.8 (VCC), IC5.38 (~SO), IC7.24 (VCC), IC21.14 (VCC), R6.1, R31.1, RP1.1 (R1); also elsewhere on the board
/CPU and ULA/A0: IC5.9 (A0); also elsewhere on the board
/CPU and ULA/A1: IC5.10 (A1); also elsewhere on the board
/CPU and ULA/A2: IC5.11 (A2); also elsewhere on the board
/CPU and ULA/A3: IC5.12 (A3); also elsewhere on the board
/CPU and ULA/A4: IC5.13 (A4); also elsewhere on the board
/CPU and ULA/A5: IC5.14 (A5); also elsewhere on the board
/CPU and ULA/A6: IC5.15 (A6); also elsewhere on the board
/CPU and ULA/A7: IC5.16 (A7); also elsewhere on the board
/CPU and ULA/A8: IC5.17 (A8), IC7.32 (A8); also elsewhere on the board
/CPU and ULA/A9: IC5.18 (A9), IC7.33 (A9); also elsewhere on the board
/CPU and ULA/A10: IC5.19 (A10), IC7.31 (A10); also elsewhere on the board
/CPU and ULA/A11: IC5.20 (A11), IC7.15 (A11); also elsewhere on the board
/CPU and ULA/A12: IC5.22 (A12), IC7.35 (A12); also elsewhere on the board
/CPU and ULA/A13: IC5.23 (A13), IC7.22 (A13); also elsewhere on the board
/CPU and ULA/A14: IC5.24 (A14), IC7.29 (A14); also elsewhere on the board
/CPU and ULA/A15: IC5.25 (A15), IC7.30 (A15); also elsewhere on the board
/CPU and ULA/D0: IC5.33 (D0), IC7.8 (D0); also elsewhere on the board
/CPU and ULA/D1: IC5.32 (D1), IC7.17 (D1); also elsewhere on the board
/CPU and ULA/D2: IC5.31 (D2), IC7.11 (D2); also elsewhere on the board
/CPU and ULA/D3: IC5.30 (D3), IC7.12 (D3); also elsewhere on the board
/CPU and ULA/D4: IC5.29 (D4), IC7.13 (D4); also elsewhere on the board
/CPU and ULA/D5: IC5.28 (D5), IC7.5 (D5); also elsewhere on the board
/CPU and ULA/D6: IC5.27 (D6), IC7.34 (D6); also elsewhere on the board
/CPU and ULA/D7: IC5.26 (D7), IC7.18 (D7); also elsewhere on the board
/CPU and ULA/MA0: IC7.38 (MA0); also elsewhere on the board
/CPU and ULA/MA1: IC7.36 (MA1); also elsewhere on the board
/CPU and ULA/MA2: IC7.37 (MA2); also elsewhere on the board
/CPU and ULA/MA3: IC7.4 (MA3); also elsewhere on the board
/CPU and ULA/MA4: IC7.3 (MA4); also elsewhere on the board
/CPU and ULA/MA5: IC7.2 (MA5); also elsewhere on the board
/CPU and ULA/MA6: IC7.40 (MA6); also elsewhere on the board
/CPU and ULA/MA7: IC7.39 (MA7); also elsewhere on the board
B: IC7.21 (BLUE); also elsewhere on the board
G: IC7.20 (GREEN); also elsewhere on the board
GND: C100.1, IC5.1 (GND), IC5.21 (GND), IC7.6 (GND), IC21.7 (GND), LK6.1, SW1.1, SW3.1; also elsewhere on the board
MUX: IC7.1 (MUX); also elsewhere on the board
unnamed: C26.1, IC21.12, R9.2
unnamed: C26.2, IC21.1, R10.1
unnamed: C100.2, IC5.6 (~NMI), R6.2, SW1.2
unnamed: IC5.37 (Ø0), IC7.14 (CLK_OUT)
unnamed: IC7.9 (CAS), IC21.9
unnamed: IC7.7 (CLK_IN), R30.2, R31.2
unnamed: IC7.10 (RAS), IC21.11
unnamed: IC7.28 (W), IC21.3
unnamed: IC21.2, R10.2, R30.1, XT1.2
unnamed: IC21.13, R9.1, XT1.1
R: IC7.19 (RED); also elsewhere on the board
ROMSEL: IC7.23 (ROMSEL); also elsewhere on the board
R/~W: IC5.34 (R/~W), IC7.27 (R/~W); also elsewhere on the board
SYNC: IC7.16 (SYNC); also elsewhere on the board
~CAS: IC21.8; also elsewhere on the board
~IRQ: IC5.4 (~IRQ); also elsewhere on the board
~I/O: IC7.25 (I/O); also elsewhere on the board
~MAP: IC7.26 (~MAP), RP1.4 (R3.2); also elsewhere on the board
~RAMW: IC21.4; also elsewhere on the board
~RAS: IC21.10; also elsewhere on the board
~RST: IC5.40 (~RES), LK6.2, SW3.2; also elsewhere on the board
Ø1: IC5.3 (Ø1); also elsewhere on the board
Ø2: IC5.39 (Ø2); also elsewhere on the board

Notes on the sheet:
Mod (p.72-9)

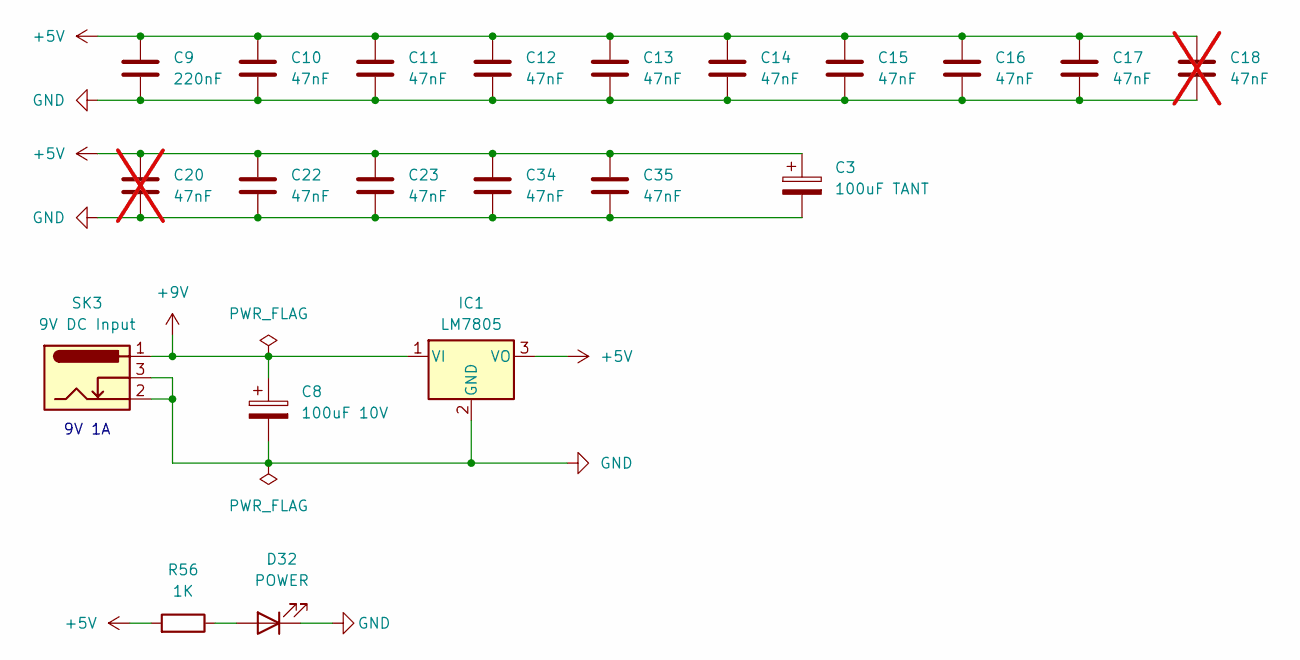
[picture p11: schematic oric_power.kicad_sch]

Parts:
C3: 100uF TANT; Tantalum Capacitor 5.00mm
C8: 100uF 10V; Electrolytic Capacitor 5.00mm
C9: 220nF; Ceramic Capacitor 5.00mm
C10, C11, C12, C13, C14, C15, C16, C17, C22, C23, C34, C35: 47nF; Ceramic Capacitor 5.00mm
C18, C20: 47nF; Ceramic Capacitor 5.00mm; not fitted
D32: POWER; LED_D3.0mm
IC1: LM7805; IC1 7805
R56: 1K; Resistor 10.16mm
SK3: 9V DC Input; SK3 Barrel Jack

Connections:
+5V: C3.1, C9.1, C10.1, C11.1, C12.1, C13.1, C14.1, C15.1, C16.1, C17.1, C18.1, C20.1, C22.1, C23.1, C34.1, C35.1, IC1.3 (VO), R56.2; also elsewhere on the board
+9V: C8.1, IC1.1 (VI), SK3.1; also elsewhere on the board
GND: C3.2, C8.2, C9.2, C10.2, C11.2, C12.2, C13.2, C14.2, C15.2, C16.2, C17.2, C18.2, C20.2, C22.2, C23.2, C34.2, C35.2, D32.1 (K), IC1.2 (GND), SK3.2, SK3.3; also elsewhere on the board
unnamed: D32.2 (A), R56.1

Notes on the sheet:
9V 1A

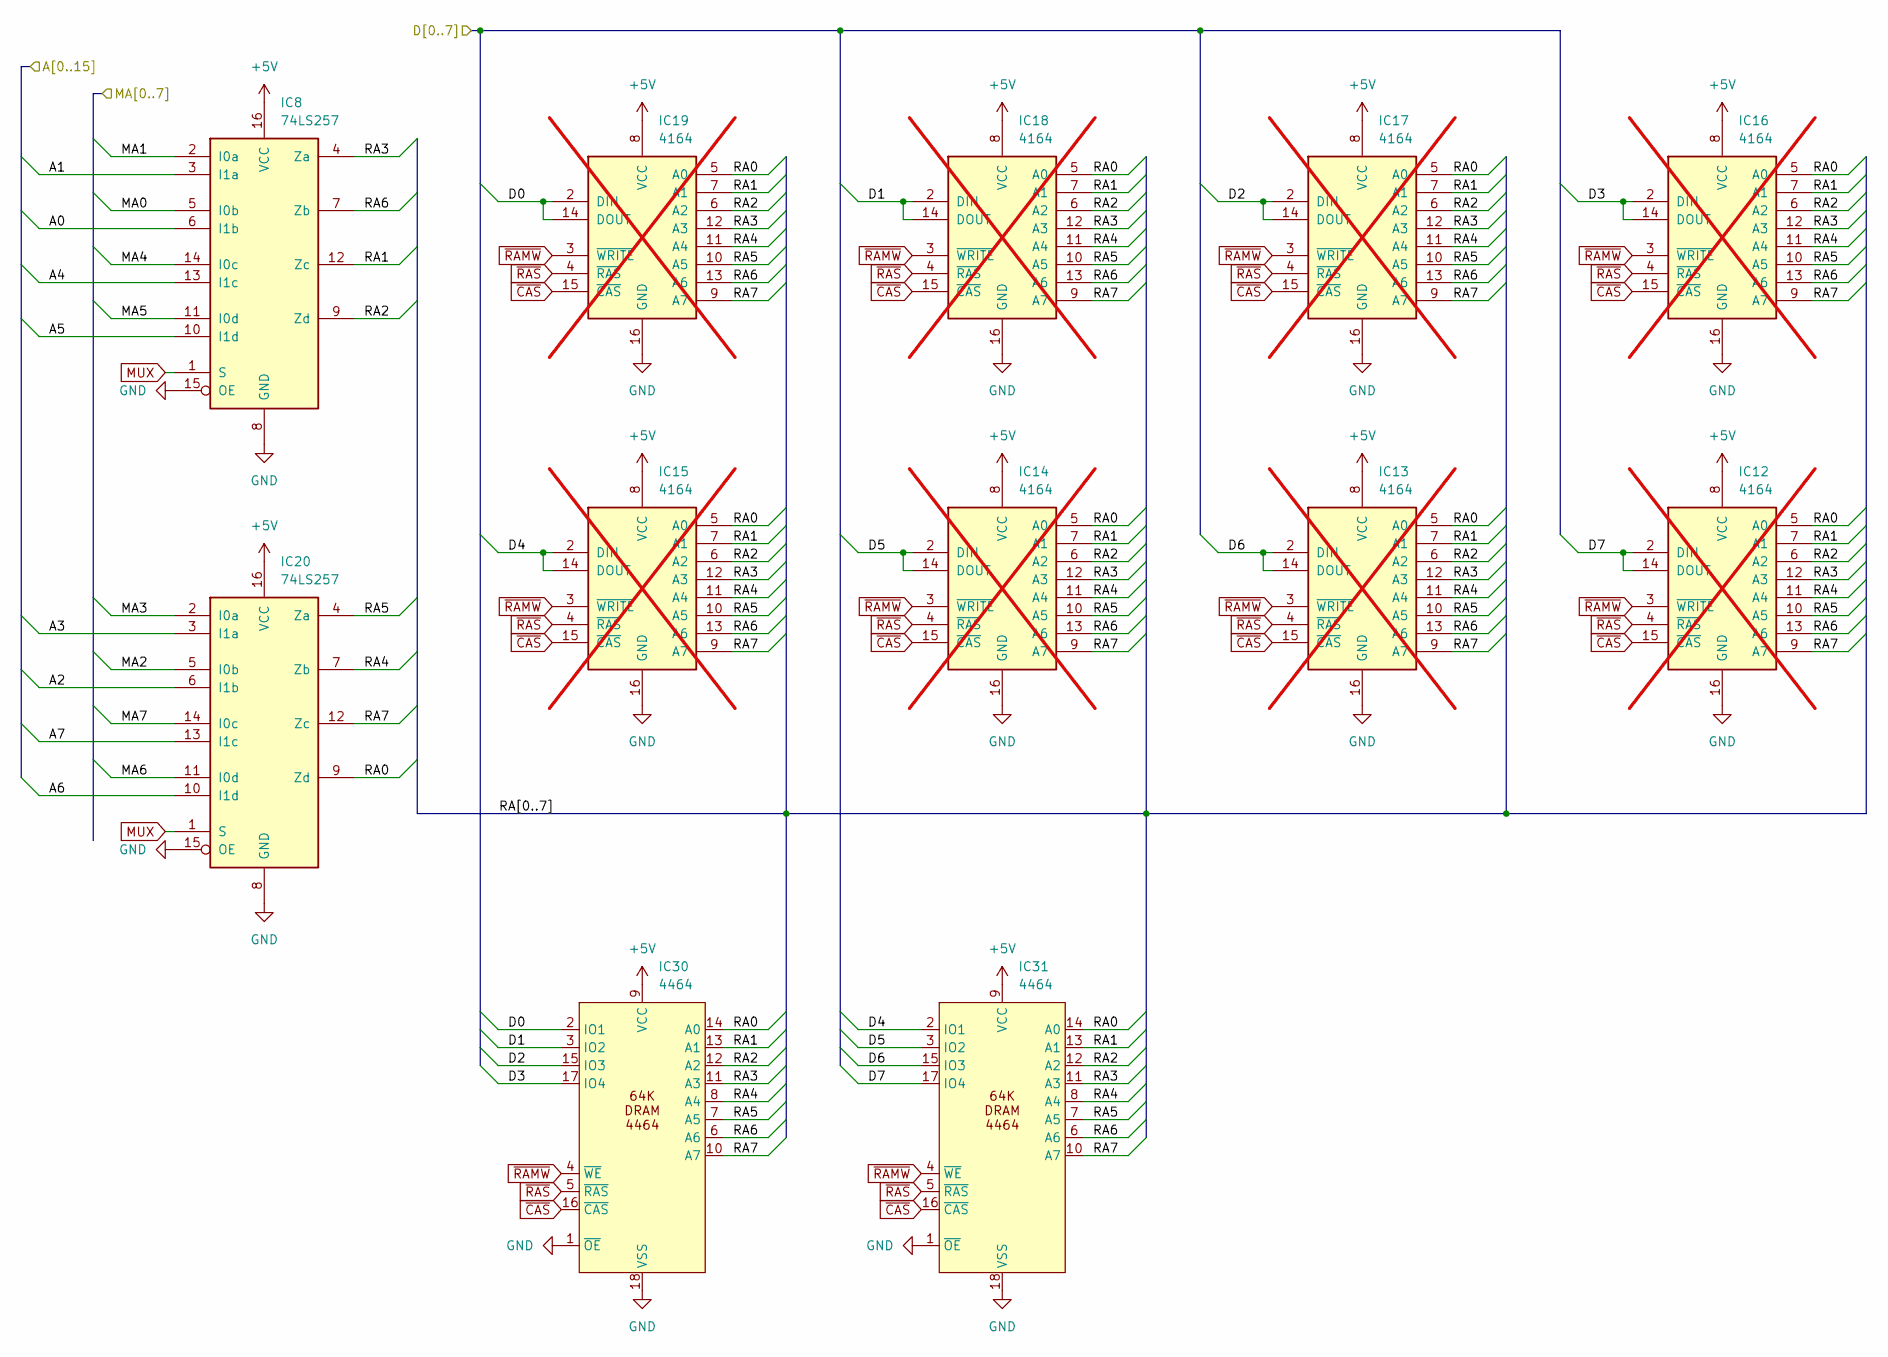
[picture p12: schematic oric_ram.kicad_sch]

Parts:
IC8, IC20: 74LS257; DIP-16_W7.62mm
IC12, IC13, IC14, IC15, IC16, IC17, IC18, IC19: 4164; DIP-16_W7.62mm; not fitted
IC30, IC31: 4464; DIP-18_W7.62mm

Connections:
+5V: IC8.16 (VCC), IC12.8 (VCC), IC13.8 (VCC), IC14.8 (VCC), IC15.8 (VCC), IC16.8 (VCC), IC17.8 (VCC), IC18.8 (VCC), IC19.8 (VCC), IC20.16 (VCC), IC30.9 (VCC), IC31.9 (VCC); also elsewhere on the board
/CPU and ULA/A0: IC8.6 (I1b); also elsewhere on the board
/CPU and ULA/A1: IC8.3 (I1a); also elsewhere on the board
/CPU and ULA/A2: IC20.6 (I1b); also elsewhere on the board
/CPU and ULA/A3: IC20.3 (I1a); also elsewhere on the board
/CPU and ULA/A4: IC8.13 (I1c); also elsewhere on the board
/CPU and ULA/A5: IC8.10 (I1d); also elsewhere on the board
/CPU and ULA/A6: IC20.10 (I1d); also elsewhere on the board
/CPU and ULA/A7: IC20.13 (I1c); also elsewhere on the board
/CPU and ULA/D0: IC19.2 (DIN), IC19.14 (DOUT), IC30.2 (IO1); also elsewhere on the board
/CPU and ULA/D1: IC18.2 (DIN), IC18.14 (DOUT), IC30.3 (IO2); also elsewhere on the board
/CPU and ULA/D2: IC17.2 (DIN), IC17.14 (DOUT), IC30.15 (IO3); also elsewhere on the board
/CPU and ULA/D3: IC16.2 (DIN), IC16.14 (DOUT), IC30.17 (IO4); also elsewhere on the board
/CPU and ULA/D4: IC15.2 (DIN), IC15.14 (DOUT), IC31.2 (IO1); also elsewhere on the board
/CPU and ULA/D5: IC14.2 (DIN), IC14.14 (DOUT), IC31.3 (IO2); also elsewhere on the board
/CPU and ULA/D6: IC13.2 (DIN), IC13.14 (DOUT), IC31.15 (IO3); also elsewhere on the board
/CPU and ULA/D7: IC12.2 (DIN), IC12.14 (DOUT), IC31.17 (IO4); also elsewhere on the board
/CPU and ULA/MA0: IC8.5 (I0b); also elsewhere on the board
/CPU and ULA/MA1: IC8.2 (I0a); also elsewhere on the board
/CPU and ULA/MA2: IC20.5 (I0b); also elsewhere on the board
/CPU and ULA/MA3: IC20.2 (I0a); also elsewhere on the board
/CPU and ULA/MA4: IC8.14 (I0c); also elsewhere on the board
/CPU and ULA/MA5: IC8.11 (I0d); also elsewhere on the board
/CPU and ULA/MA6: IC20.11 (I0d); also elsewhere on the board
/CPU and ULA/MA7: IC20.14 (I0c); also elsewhere on the board
/RAM/RA0: IC12.5 (A0), IC13.5 (A0), IC14.5 (A0), IC15.5 (A0), IC16.5 (A0), IC17.5 (A0), IC18.5 (A0), IC19.5 (A0), IC20.9 (Zd), IC30.14 (A0), IC31.14 (A0)
/RAM/RA1: IC8.12 (Zc), IC12.7 (A1), IC13.7 (A1), IC14.7 (A1), IC15.7 (A1), IC16.7 (A1), IC17.7 (A1), IC18.7 (A1), IC19.7 (A1), IC30.13 (A1), IC31.13 (A1)
/RAM/RA2: IC8.9 (Zd), IC12.6 (A2), IC13.6 (A2), IC14.6 (A2), IC15.6 (A2), IC16.6 (A2), IC17.6 (A2), IC18.6 (A2), IC19.6 (A2), IC30.12 (A2), IC31.12 (A2)
/RAM/RA3: IC8.4 (Za), IC12.12 (A3), IC13.12 (A3), IC14.12 (A3), IC15.12 (A3), IC16.12 (A3), IC17.12 (A3), IC18.12 (A3), IC19.12 (A3), IC30.11 (A3), IC31.11 (A3)
/RAM/RA4: IC12.11 (A4), IC13.11 (A4), IC14.11 (A4), IC15.11 (A4), IC16.11 (A4), IC17.11 (A4), IC18.11 (A4), IC19.11 (A4), IC20.7 (Zb), IC30.8 (A4), IC31.8 (A4)
/RAM/RA5: IC12.10 (A5), IC13.10 (A5), IC14.10 (A5), IC15.10 (A5), IC16.10 (A5), IC17.10 (A5), IC18.10 (A5), IC19.10 (A5), IC20.4 (Za), IC30.7 (A5), IC31.7 (A5)
/RAM/RA6: IC8.7 (Zb), IC12.13 (A6), IC13.13 (A6), IC14.13 (A6), IC15.13 (A6), IC16.13 (A6), IC17.13 (A6), IC18.13 (A6), IC19.13 (A6), IC30.6 (A6), IC31.6 (A6)
/RAM/RA7: IC12.9 (A7), IC13.9 (A7), IC14.9 (A7), IC15.9 (A7), IC16.9 (A7), IC17.9 (A7), IC18.9 (A7), IC19.9 (A7), IC20.12 (Zc), IC30.10 (A7), IC31.10 (A7)
GND: IC8.8 (GND), IC8.15 (OE), IC12.16 (GND), IC13.16 (GND), IC14.16 (GND), IC15.16 (GND), IC16.16 (GND), IC17.16 (GND), IC18.16 (GND), IC19.16 (GND), IC20.8 (GND), IC20.15 (OE), IC30.1 (~OE), IC30.18 (VSS), IC31.1 (~OE), IC31.18 (VSS); also elsewhere on the board
MUX: IC8.1 (S), IC20.1 (S); also elsewhere on the board
~CAS: IC12.15 (~CAS), IC13.15 (~CAS), IC14.15 (~CAS), IC15.15 (~CAS), IC16.15 (~CAS), IC17.15 (~CAS), IC18.15 (~CAS), IC19.15 (~CAS), IC30.16 (~CAS), IC31.16 (~CAS); also elsewhere on the board
~RAMW: IC12.3 (~WRITE), IC13.3 (~WRITE), IC14.3 (~WRITE), IC15.3 (~WRITE), IC16.3 (~WRITE), IC17.3 (~WRITE), IC18.3 (~WRITE), IC19.3 (~WRITE), IC30.4 (~WE), IC31.4 (~WE); also elsewhere on the board
~RAS: IC12.4 (~RAS), IC13.4 (~RAS), IC14.4 (~RAS), IC15.4 (~RAS), IC16.4 (~RAS), IC17.4 (~RAS), IC18.4 (~RAS), IC19.4 (~RAS), IC30.5 (~RAS), IC31.5 (~RAS); also elsewhere on the board

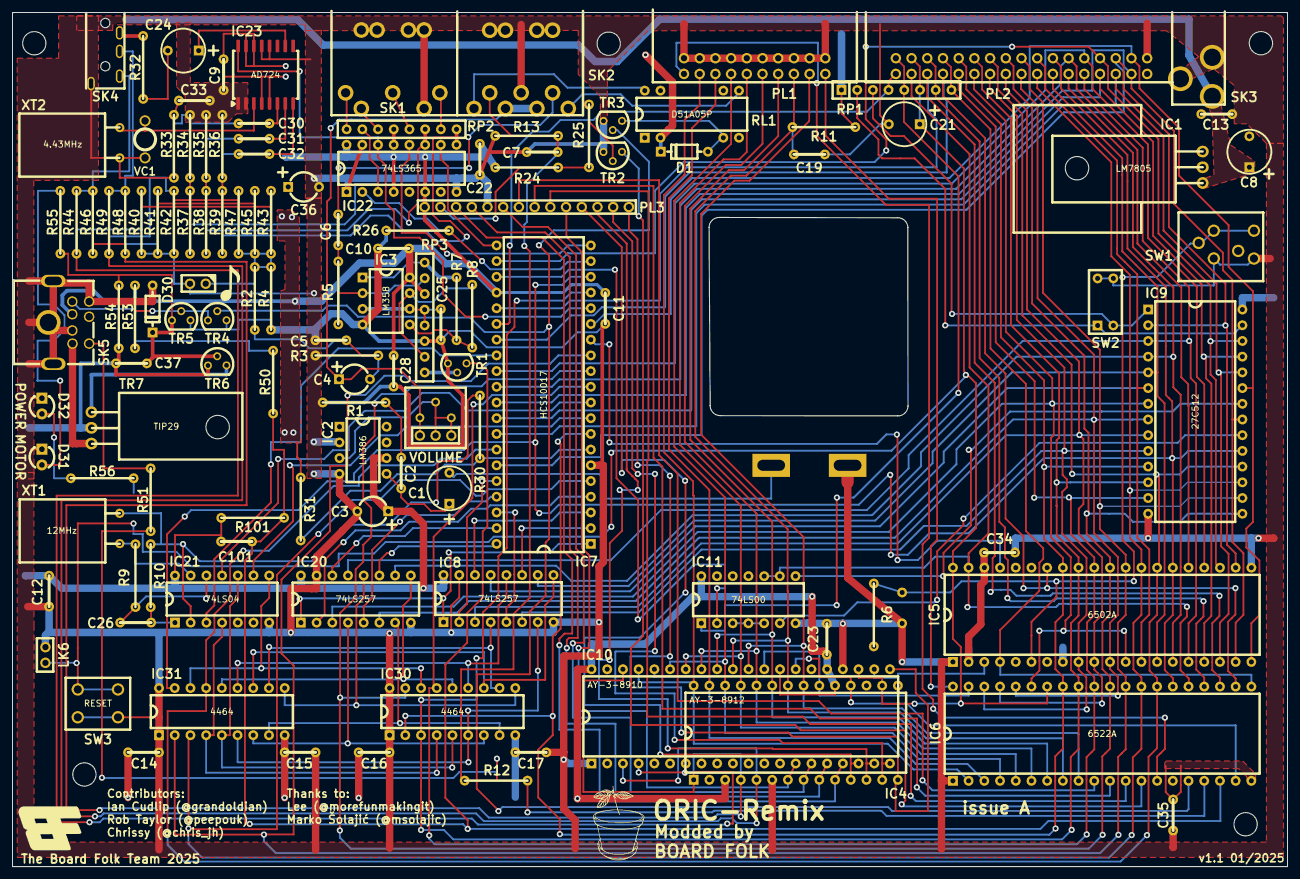
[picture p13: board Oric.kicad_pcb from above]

Board: 2 copper layers, 206.2 x 138.1 mm, 132 parts (1 on the bottom side), 155 nets.

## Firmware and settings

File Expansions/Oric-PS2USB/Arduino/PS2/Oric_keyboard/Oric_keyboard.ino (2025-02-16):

/*
  Orickeyboard - Oric Keyboard Library
  Adapted by Ian Cudlip
  v0 11/11/2024

  Based on C64keyboard - Commodore Keyboard library by Hartland PC LLC
  Copyright (c) 2022 Hartland PC LLC
  Written by Robert VanHazinga

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
  You should have received a copy of the GNU Lesser General Public
  License along with this library; if not, write to the Free Software
  Foundation, Inc., 51 Franklin St, Fifth Floor, Boston, MA  02110-1301  USA
*/

#include <PS2KeyAdvanced.h>
#include "Orickeyboard.h"

PS2KeyAdvanced keyboard;
Orickeyboard ckey;
static volatile uint8_t  currkeymap = 1, flags ;
static const OricKeymap_t *keymap = NULL;
static volatile bool lshift=false, rshift=false, capslock=false;

void setup() {
  // Configure the keyboard library
  keyboard.begin( DATA_PIN, IRQ_PIN );
  keyboard.setNoRepeat (1);
  keyboard.setNoBreak (0);
  ckey.begin();
 if (debug) {Serial.begin( 9600 );
 Serial.println("Startup..");
 }
}

void loop() {
 if ( keyboard.available() )
 {
   Orickey(keyboard.read());  
 }
}

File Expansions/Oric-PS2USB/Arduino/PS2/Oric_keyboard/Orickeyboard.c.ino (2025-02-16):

/*
  Orickeyboard - Oric Keyboard Library
  Adapted by Ian Cudlip

  Based on C64keyboard - Commodore Keyboard library by Hartland PC LLC
  Copyright (c) 2022 Hartland PC LLC
  Written by Robert VanHazinga

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
  You should have received a copy of the GNU Lesser General Public
  License along with this library; if not, write to the Free Software
  Foundation, Inc., 51 Franklin St, Fifth Floor, Boston, MA  02110-1301  USA
*/
#include "Orickeyboard.h"

void resetMT88(void) {
  digitalWrite(ANALOG_SW_DATA , LOW);
  digitalWrite(ANALOG_SW_RESET, HIGH);
  digitalWrite( ANALOG_SW_STROBE, HIGH);
  digitalWrite(ANALOG_SW_RESET, LOW);
  digitalWrite( ANALOG_SW_STROBE, LOW);
  digitalWrite(ANALOG_SW_DATA , HIGH);
  keyboard.setLock (PS2_LOCK_SCROLL && 0);
  capslock = false;
  lshift = false;
  rshift = false;
  currkeymap = 1;
  }

void setswitch(uint16_t c){
  int bitr;
  bool state;
  
  // Fix logic table hole in MT8812/16 and things
  // AX3 line control. There must be a more logical way of working this out.
  if (!MT8808) {
    // any required modifiers here, hopefully none.
    if (c>63) {
      digitalWrite(ANALOG_SW_AX3, LOW);
    } else {
      digitalWrite(ANALOG_SW_AX3, HIGH);
    }
  }

  if (debug){
    Serial.println(c);
  }
  
  if (c < 160) {
    for ( int currentPin = ANALOG_SW_ARRAY_START; currentPin <= ANALOG_SW_ARRAY_END; ++currentPin) {
      bitr = (currentPin - ANALOG_SW_ARRAY_START);
      state =  bitRead(c, bitr);
      digitalWrite(currentPin, state);
    }
    digitalWrite( ANALOG_SW_STROBE, HIGH);
    digitalWrite( ANALOG_SW_STROBE, LOW);
  }
  if (!MT8808){digitalWrite(ANALOG_SW_AX3, LOW);}

}

void setfswitch(uint16_t c){
  int bitr;
  bool state;
  
   digitalWrite(ANALOG_SW_AX3, HIGH);

  if (c < 160) {
    for ( int currentPin = ANALOG_SW_ARRAY_START; currentPin <= ANALOG_SW_ARRAY_END; ++currentPin) {
      bitr = (currentPin - ANALOG_SW_ARRAY_START);
      state =  bitRead(c, bitr);
      digitalWrite(currentPin, state);
    }
    digitalWrite( ANALOG_SW_STROBE, HIGH);
    digitalWrite( ANALOG_SW_STROBE, LOW);
  }
  
  digitalWrite(ANALOG_SW_AX3, LOW);

}

void debugkey (uint16_t c,uint8_t flags,uint8_t kc){
    Serial.print ("Oric Keycode: ");
    Serial.print (c);
    Serial.print ("  (ASCII Code: ");
    Serial.print (kc);
    Serial.print (" Hex: ");
    Serial.print (kc, HEX);
    Serial.print (")  Flags: ");
      for (int i = 7; i >= 0; i--)
    {
        bool b = bitRead(flags, i);
        Serial.print(b);
    }
    Serial.println();
  }
    
void Orickey(uint16_t k) {
   flags = k >> 8;
   uint8_t kc= k & 0xFF;
   uint16_t c = 0;

  if (currkeymap == 2) {
    if (bitRead(flags, 6)) {
      c = pgm_read_word(keymap->shift_2 + kc);
    }
    else {
      c = pgm_read_word(keymap->noshift_2 + kc);
    }
  }

   if (currkeymap == 1) {
    if (bitRead(flags, 6)) {
      c = pgm_read_word(keymap->shift_1 + kc);
    }
    else {
      c = pgm_read_word(keymap->noshift_1 + kc);
    }
  }
  
//  debug output
    if (debug){debugkey(c,flags,kc);}

// Ignore extended codes 
    if (kc == 250){
      if (debug){
        Serial.println("Ignore");
      }
      c=IGNORE_KEYCODE;
      }

 
// MT reset function    
    if (kc == MT_RESET) {
    resetMT88();  
    c=IGNORE_KEYCODE;
   }   
    
// Capslock function 

    if (kc == CAPSLOCK_KEY) {
      capslock = !capslock;
      if (debug) {
        if (capslock)  {
          Serial.println("Caps Lock On");
        } else {
          Serial.println("Caps Lock Off");
        }
      }
      
      digitalWrite (ANALOG_SW_DATA, HIGH);
      setswitch(6);
      delay(100);
      digitalWrite (ANALOG_SW_DATA, LOW);
      setswitch(6);
      c = IGNORE_KEYCODE; 
      }


// Keymap Handling
    if (kc == KEY_MAP_1 && !bitRead(flags,7)){
      currkeymap = 1;
      keyboard.setLock (PS2_LOCK_SCROLL && 0);
      }

    if (kc == KEY_MAP_2 && !bitRead(flags,7)){
      currkeymap = 2;
      keyboard.setLock (PS2_LOCK_SCROLL && 1);
      }
        
// Jump to end if key code is an ignored key
    if (c != IGNORE_KEYCODE) {
    //  Differential shift conversion during key press
   if (c >= 160 ) {
      c -= 160;
      if (rshift || lshift) {
        //digitalWrite (ANALOG_SW_DATA, LOW);
        //setswitch(OricRSHFT);      (lets not set the right shift, as for some reasons enter gets pressed)
        digitalWrite (ANALOG_SW_DATA, LOW);
        setswitch(OricLSHFT);   
      }
      
     else {
        digitalWrite (ANALOG_SW_DATA, HIGH);
        setswitch(OricLSHFT);
      }
      // Set cross switch key
      digitalWrite(ANALOG_SW_DATA, HIGH);
      setswitch(c);
       if bitRead (flags,7){
      // Restore shift state to match keystate
      digitalWrite (ANALOG_SW_DATA, lshift);
      setswitch(OricLSHFT);
//      digitalWrite (ANALOG_SW_DATA, rshift);
//      setswitch(OricRSHFT);
      digitalWrite(ANALOG_SW_DATA, HIGH);
     }
   }
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

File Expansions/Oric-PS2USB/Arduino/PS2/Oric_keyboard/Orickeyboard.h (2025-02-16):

/*
  Orickeyboard - Oric Keyboard Library
  Adapted by Ian Cudlip

  Based on C64keyboard - Commodore Keyboard library by Hartland PC LLC
  Copyright (c) 2022 Hartland PC LLC
  Written by Robert VanHazinga

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
  You should have received a copy of the GNU Lesser General Public
  License along with this library; if not, write to the Free Software
  Foundation, Inc., 51 Franklin St, Fifth Floor, Boston, MA  02110-1301  USA
*/

#ifndef Orickeyboard_h
#define Orickeyboard_h

#if defined(ARDUINO) && ARDUINO >= 100
#include "Arduino.h"
#else
#include "WProgram.h"
#endif
#define Oric_KEYMAP_SIZE 	   152 // Size of each array in the key maps

#include "keymapping.h"

#define debug   false     // Set true for serial monitor of Oric keycodes and PS/2 keycodes

#define MT8808  false    // This has to be set to false now as we use more lines than the MT8808 provides

//PS2 communication pins
#define DATA_PIN				12 // Data pin for PS2 keyboard
#define IRQ_PIN					3  // Interrupt pin for PS2 keyboard

//Scan code value to enable a key map. Default is key map 1.
#define KEY_MAP_1				0x6B // F11?
#define KEY_MAP_2				0x6C // F12?

//Key map value to ignore key press
#define IGNORE_KEYCODE			0x154 //(DEC 340) (Must be > 128)

// Key map value to reset the MT88xx chip
#define MT_RESET        0x6C // (DEC 108) F12 activates MT88XX reset

//MT88xx control pins
#define ANALOG_SW_DATA      2 // Sets selected cross switch on/off (Old 13)
#define ANALOG_SW_STROBE    4 // Strobe timing pulse
#define ANALOG_SW_RESET     13 // Reset all MT88XX cross switches to off (Old 2)
#define ANALOG_SW_ARRAY_START 5 // First pin of 6 bit switch addressing. AY2-0 & AX2-0
#define ANALOG_SW_ARRAY_END   10 // Last pin of 6 bit switch addressing. AY2-0 & AX2-0
#define ANALOG_SW_AX3     11 // Pin that controls AX3 (MT8812 & MT8816) 

//Oric Break Key
#define OricBREAK_PIN     A0

// Key map value for capslock
#define CAPSLOCK_KEY    0x03 // CapsLock key 

#define OricLSHFT  73
#define OricRSHFT  79

#define OricBREAK  4

class Orickeyboard {
  public:
    Orickeyboard();
    
    static void begin(const OricKeymap_t &map = OricKeymap_main);
};
#endif
